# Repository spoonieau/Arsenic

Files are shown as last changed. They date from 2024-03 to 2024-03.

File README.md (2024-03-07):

# Smart HVAC Probe

A ESP32-C3 based probe designed for the the automatic matching of r1234yf, r134, HC-30 and R744 refrigerant pressures from current atmospheric temperature.

## Features
This Probe is designed for the the automatic matching of r1234yf, r134, HC-30 and R744 refrigerant pressures from current atmospheric temperature.

It is also equipped with a vent probe for use automotive air conditioning performance testing.

Charged and programmed over USB -C 

The probe is a fully enabled WiFi device hosting its own micro web server to to display sensor and pressure data. Any device with a WiFi connection and a web browser can connect. 

Once booted the probe will broadcast a WiFi Connection with the details below.

SSID: Smart_Hvac_Probe  
Default Password: Smart_Hvac_Probe  
Probes IP: 192.168.4.1  

Once WiFi connection is established between probe and device, a device the web browser should redirect you the the hosted probes home page. If not, type the probes IP address into a connect web browser address bar.
 
Once at the Probes homepage you can change the WiFi details and set the default units to used by the probe.  
When any setting are updated the Probe will reboot and you device will need to reconnect with the new details. 

## Screenshots
PCB_V3_EE  
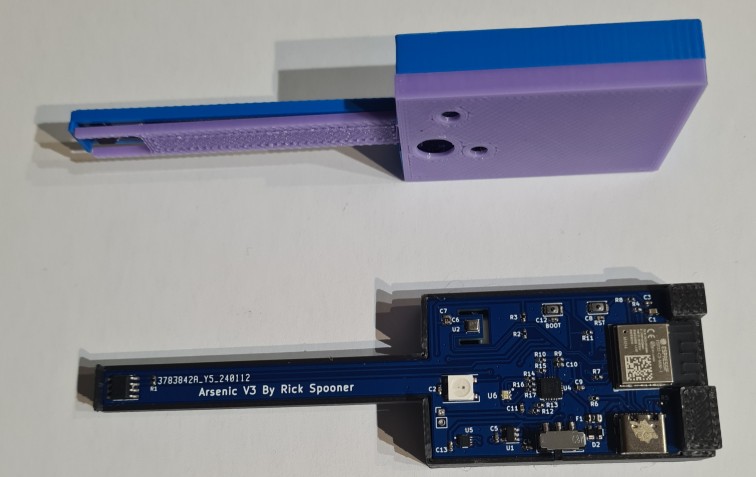
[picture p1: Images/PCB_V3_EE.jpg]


FireFox Mobile  
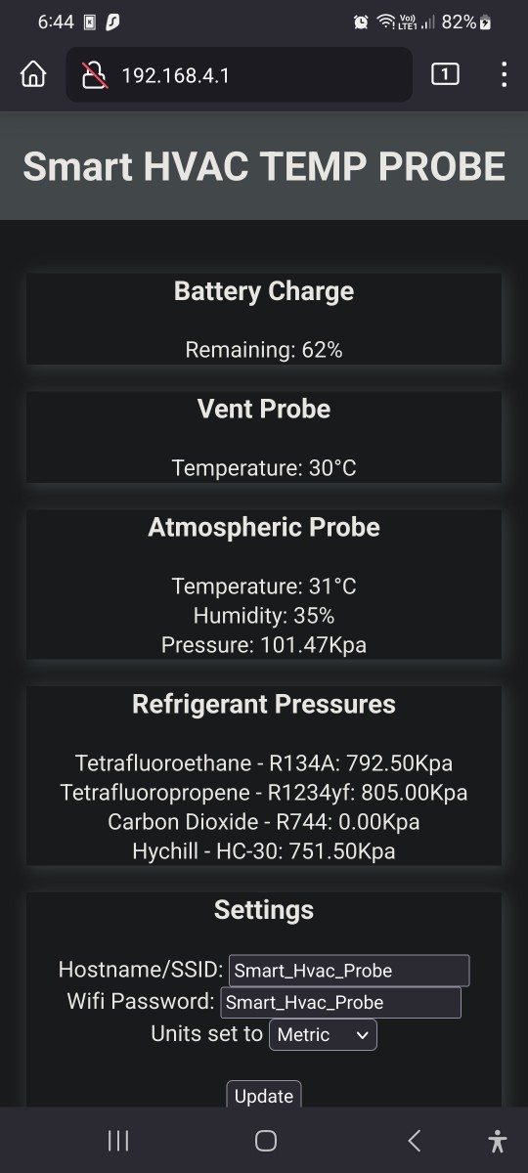
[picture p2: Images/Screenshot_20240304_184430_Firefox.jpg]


FireFox PC  
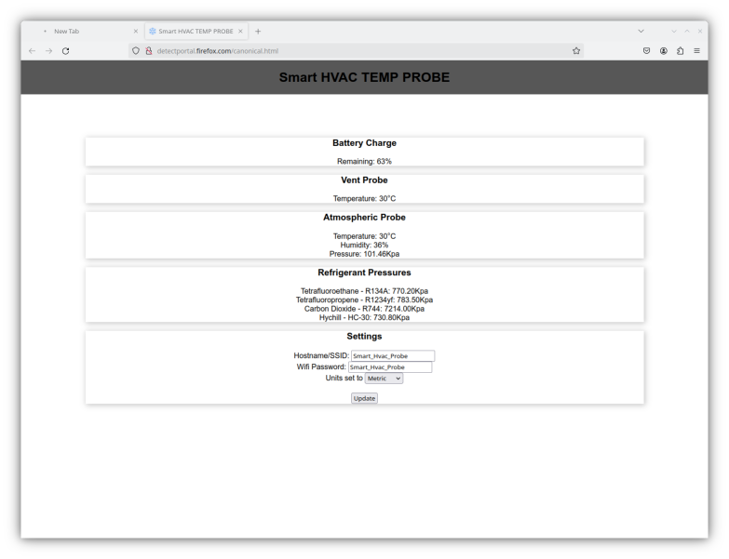
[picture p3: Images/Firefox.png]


## Used Libraries
A huge thankyou to the authors of the libraries used below.  

PaulStoffregen - OneWire  
https://github.com/PaulStoffregen/OneWire

milesburton - Arduino-Temperature-Control-Library  
https://github.com/milesburton/Arduino-Temperature-Control-Library

RadioShuttle - WS2812Led  
https://github.com/RadioShuttle/WS2812Led

hideakitai - MAX17048  
https://github.com/hideakitai/MAX17048

malokhvii-eduard - arduino-bme280  
https://github.com/malokhvii-eduard/arduino-bme280

me-no-dev - ESPAsyncWebServer  
https://github.com/me-no-dev/ESPAsyncWebServer

me-no-dev - AsyncTCP  
https://github.com/me-no-dev/AsyncTCP

arduino-libraries   
https://github.com/arduino-libraries

espressif - arduino-esp32  
https://github.com/espressif/arduino-esp32

## License

Libraries that are used carry their own Licenses.  
Project is released under GPL3

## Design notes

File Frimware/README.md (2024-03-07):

Arsenic Smart HVAC Probe Frimware  
Current is 0.2v for PCB V3

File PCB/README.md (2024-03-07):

KiCad PCB design files for Arsenic Smart HAVC Probe   
Current working version V3

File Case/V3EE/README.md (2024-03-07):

Quick and dirty case made in FreeCad for Arsenic PCB V3

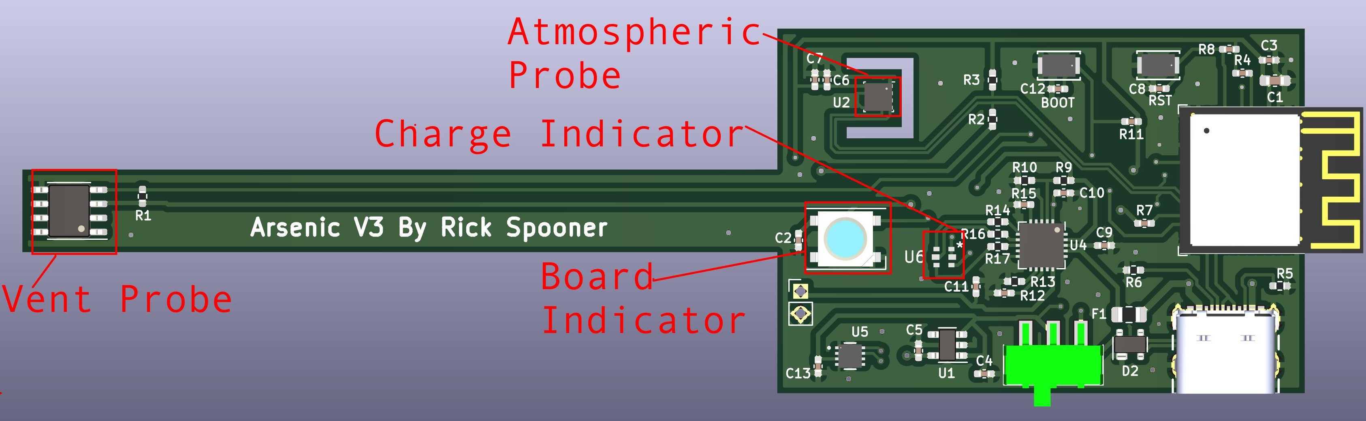
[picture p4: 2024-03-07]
Images/Arsenicv3light.jpg

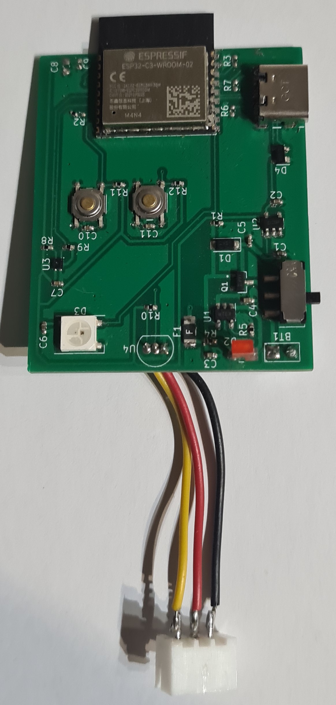
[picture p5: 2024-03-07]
Images/PCB_V1.jpg

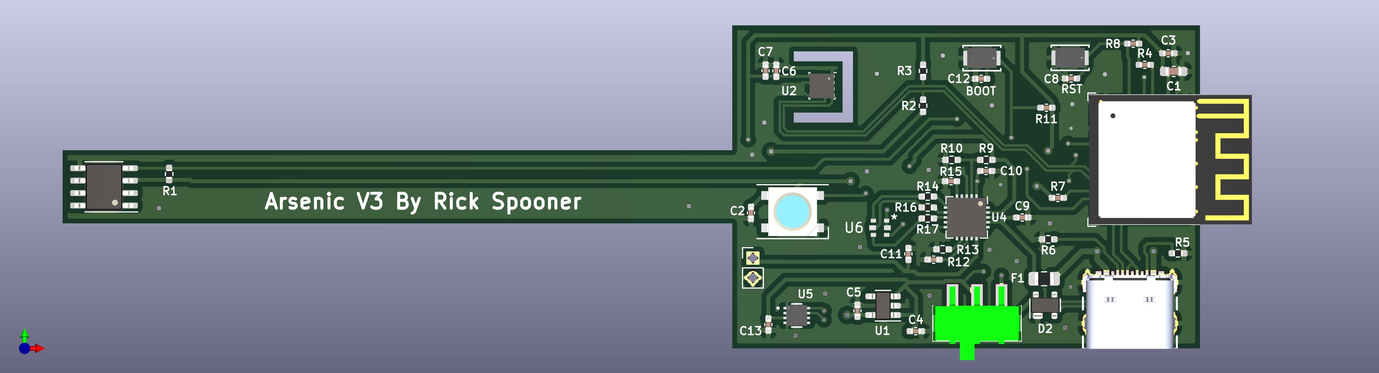
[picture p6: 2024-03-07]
Images/Arsenicv3.jpg

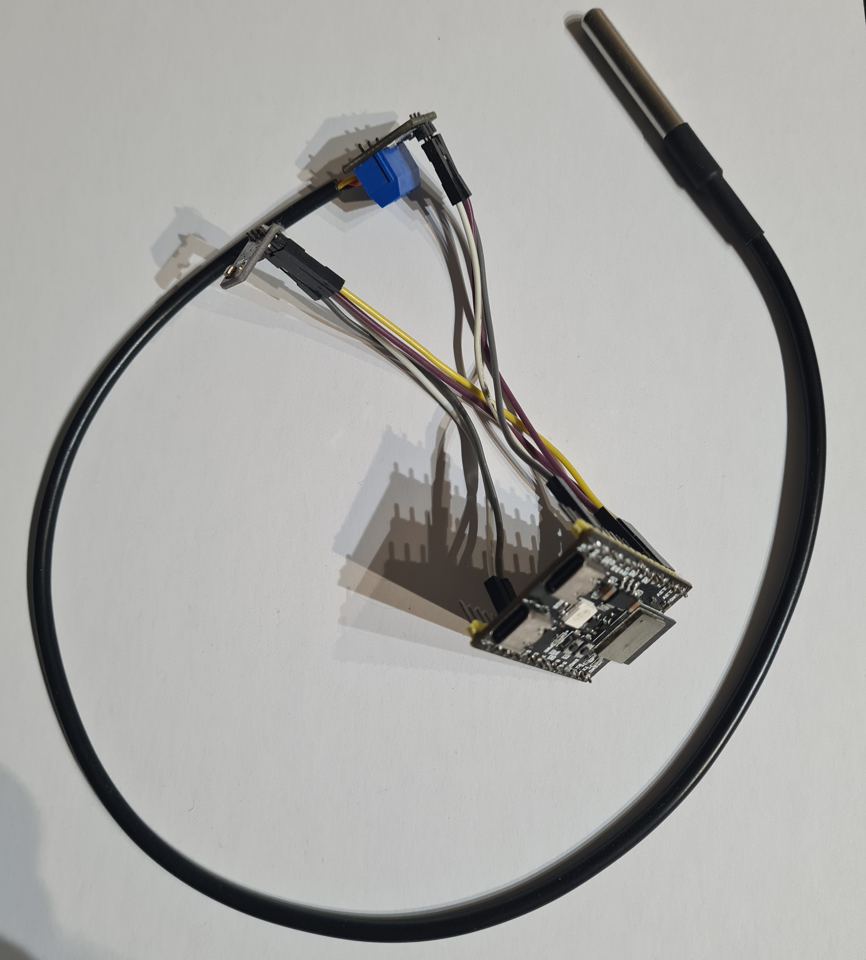
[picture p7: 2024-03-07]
Images/POC_PCB.jpg

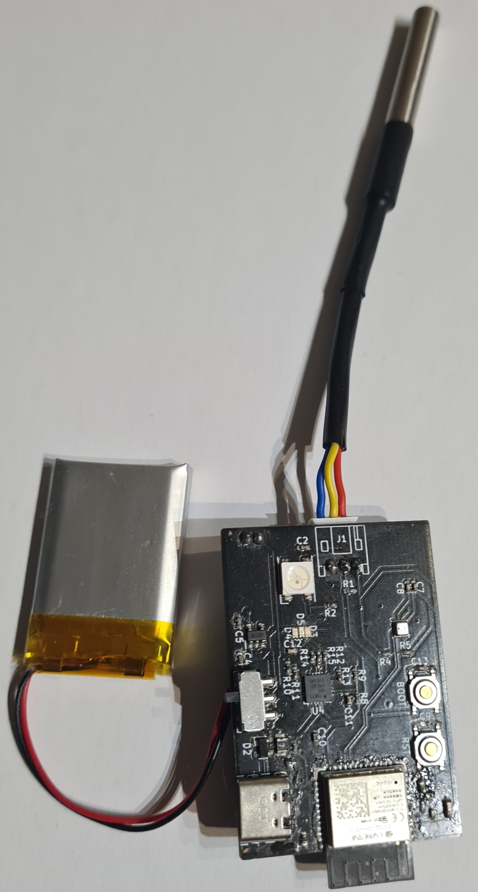
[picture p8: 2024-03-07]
Images/PCV_V2.jpg

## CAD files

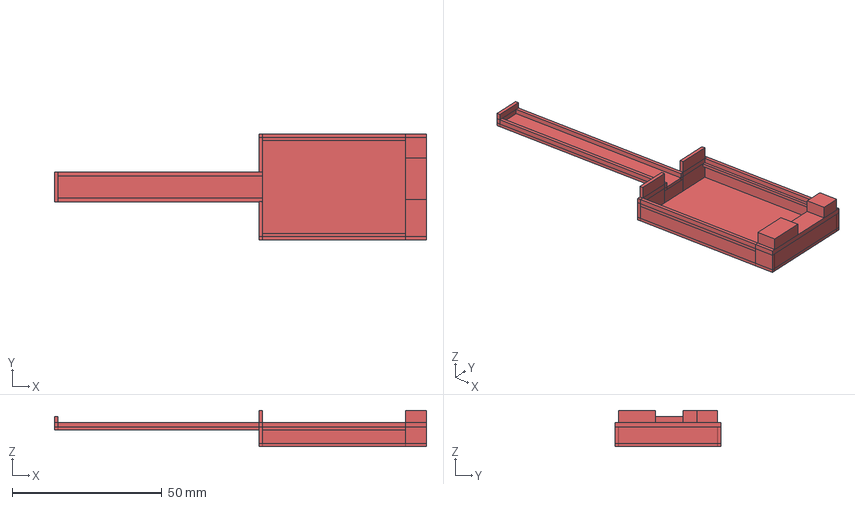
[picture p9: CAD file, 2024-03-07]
Case/V3EE/Arsenic-Case-Bottom.FCStd
124.2 x 35.4 x 12.1 mm
Ruled_Surface
Ruled_Surface001
Ruled_Surface002
Ruled_Surface003
Ruled_Surface004
Ruled_Surface005
Ruled_Surface006
Ruled_Surface007
Ruled_Surface008

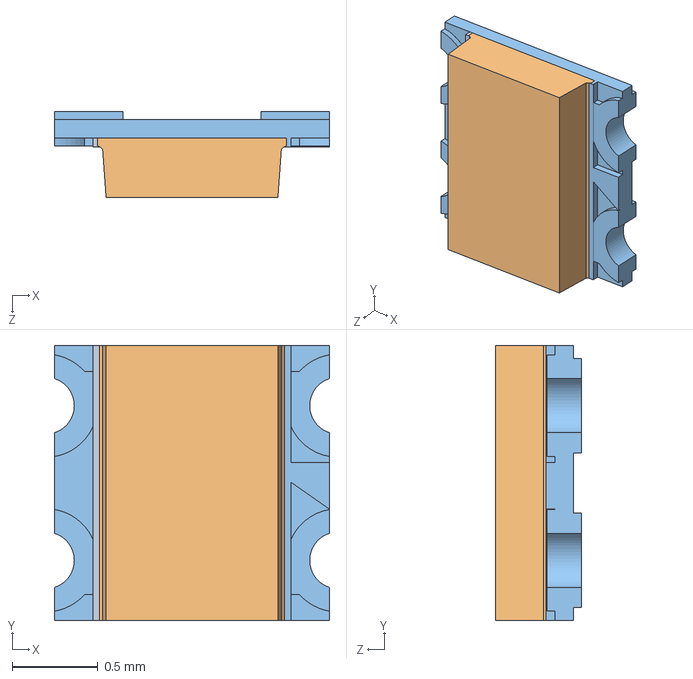
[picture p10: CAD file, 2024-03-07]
PCB/Arsenicv3/Footprints/EAST1616RGBA8/EAST1616RGBA0.STEP
1.60 x 1.60 x 0.5 mm

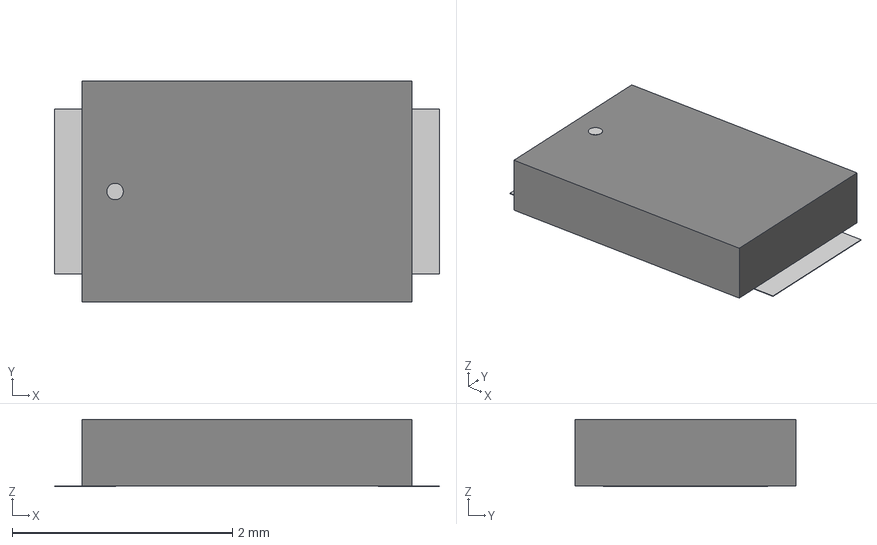
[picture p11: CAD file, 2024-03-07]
PCB/Arsenicv3/Footprints/KXT 331 LHS/KXT321LHS_CNK.step
3.50 x 2.01 x 0.612 mm

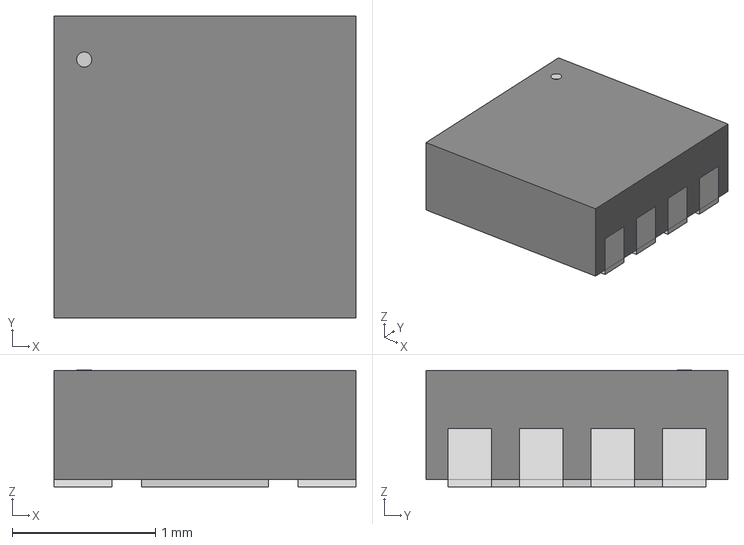
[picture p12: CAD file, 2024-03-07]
PCB/Arsenicv3/Footprints/MAX17048G/21-0168E_T822-3_MXM.step
2.11 x 2.11 x 0.815 mm

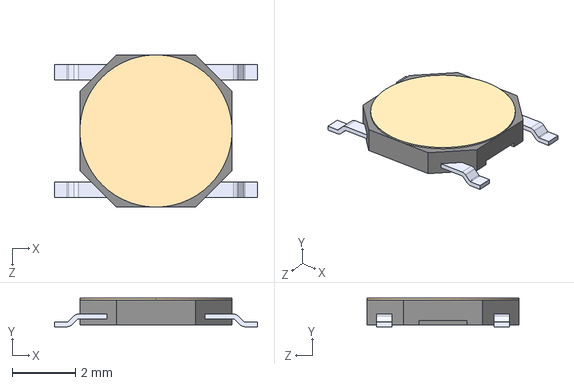
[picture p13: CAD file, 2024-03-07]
PCB/Arsenicv3/Footprints/PTS526_SM15_SMTR2_LFS/PTS526 SM08 SMTR2 LFS--3DModel-STEP-56544.STEP
6.40 x 0.9 x 4.80 mm

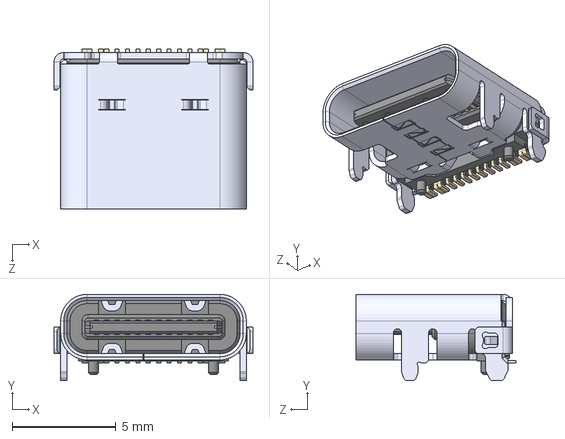
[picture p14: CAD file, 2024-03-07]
PCB/Arsenicv3/Footprints/USB4105-GF-A/USB4105-GF-A.step
9.58 x 4.16 x 7.71 mm

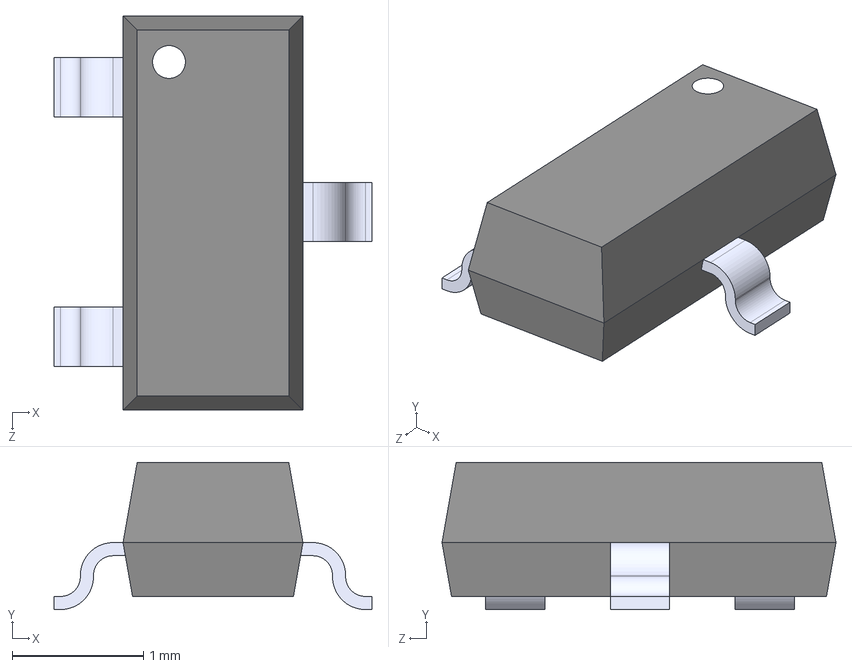
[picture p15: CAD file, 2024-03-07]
PCB/Arsnic/FootPrints/DMP1045U/DMP1045U.step
2.42 x 1.12 x 3.00 mm

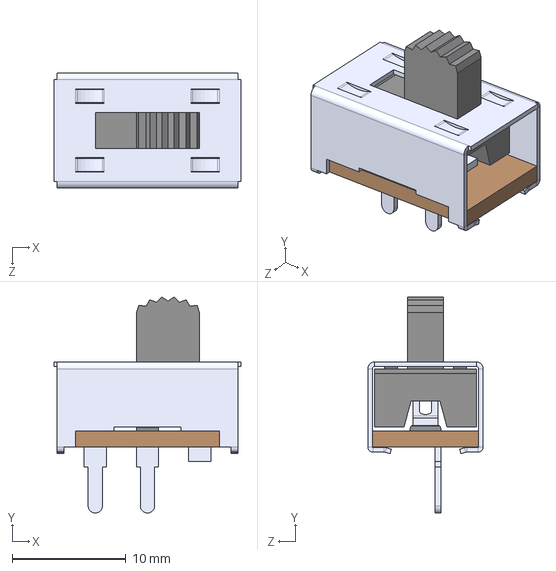
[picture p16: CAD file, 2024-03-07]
PCB/Arsnic/FootPrints/GF-123-0054/GF-123-0054.step
16.5 x 19.0 x 10.2 mm

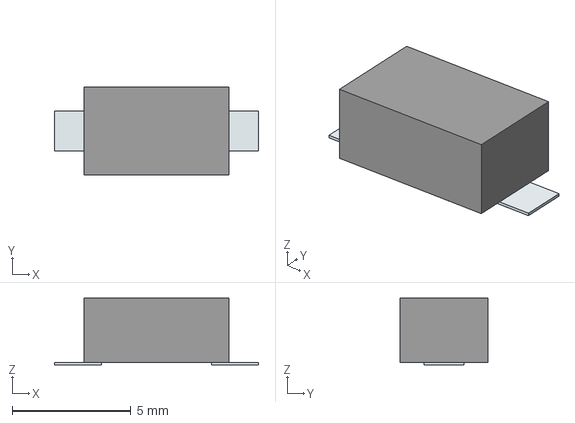
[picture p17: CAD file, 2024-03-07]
PCB/Arsnic/FootPrints/PTS636_SM25F_SMTR_LFS/PTS636_SM25F_SMTR_LFS.step
8.58 x 3.70 x 2.80 mm
Pins

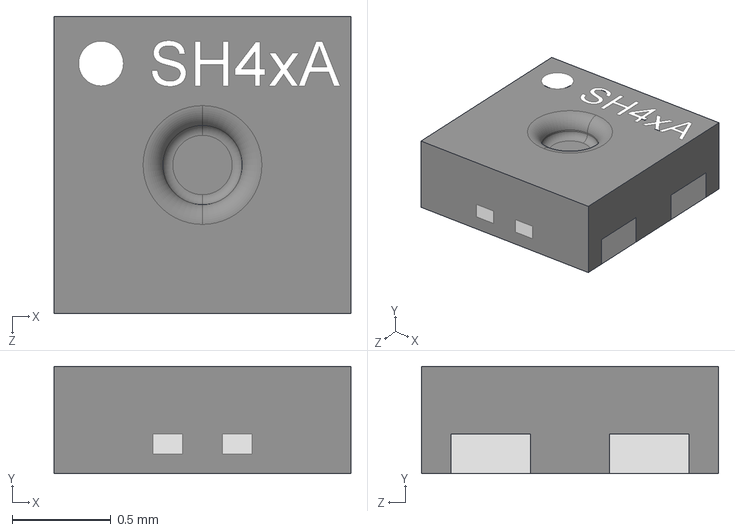
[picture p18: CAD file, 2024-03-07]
PCB/Arsnic/FootPrints/SHT40-AD1B-R3/SHT40-AD1B-R3.step
1.50 x 0.541 x 1.50 mm

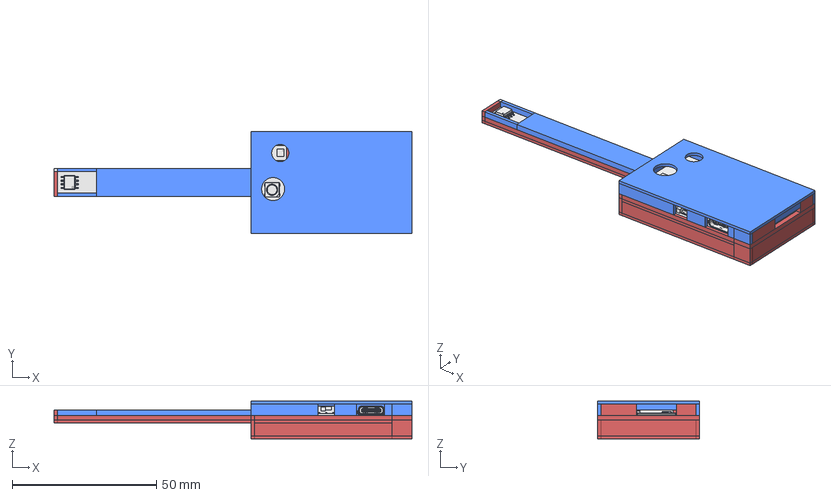
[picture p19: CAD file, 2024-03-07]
Case/V3EE/Arsenic-Case.FCStd
124.2 x 35.4 x 13.1 mm
JS102011SAQN_SW0004_PRT
USB4105
USB4106
USB4107
USB4108
USB4109
USB4110
USB4111
USB4112
USB4113
USB4114
USB4115
USB4116
USB4117
USB4118
USB4119
USB4120
USB4121
USB4122
USB4123
USB4124
USB4125
USB4126
USB4127
USB4128
USB4129
USB4130
USB4131
USB4132
USB4133
USB4134
USB4135
USB4136
USB4137
USB4138
USB4139
USB4140
USB4141
USB4142
USB4143
USB4144
USB4145
USB4146
USB4147
USB4148
ESP32-C3-MINI-1
ESP32-C3-MINI-002
ESP32-C3-MINI-003
ESP32-C3-MINI-004
ESP32-C3-MINI-005
ESP32-C3-MINI-006
ESP32-C3-MINI-007
ESP32-C3-MINI-008
ESP32-C3-MINI-009
ESP32-C3-MINI-010
ESP32-C3-MINI-011
ESP32-C3-MINI-012
ESP32-C3-MINI-013
ESP32-C3-MINI-014
ESP32-C3-MINI-015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

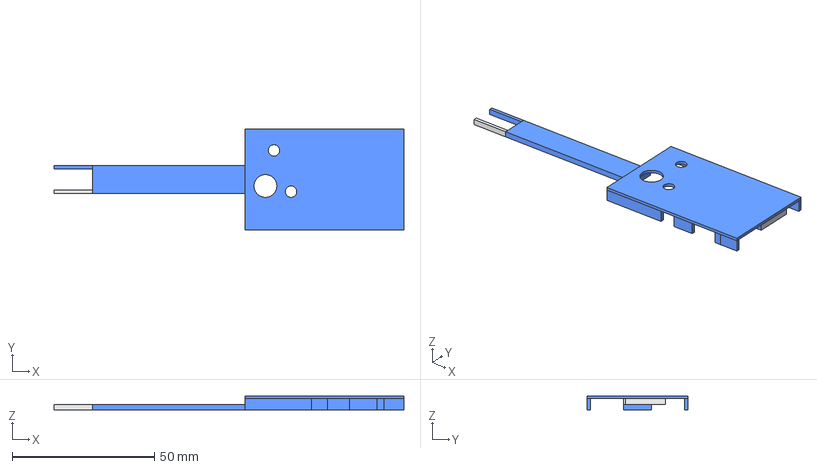
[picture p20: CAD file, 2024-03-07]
Case/V3EE/Arsenic-Case-Top.FCStd
123.0 x 35.4 x 5.00 mm
Ruled_Surface034

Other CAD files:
PCB/Arsenicv3/Footprints/3d/BQ24040DSQR.step
PCB/Arsenicv3/Footprints/3d/JS102011SAQN.step
PCB/Arsenicv3/Footprints/BQ24040DSQR/BQ24040DSQR.step
PCB/Arsenicv3/Footprints/JS102011SAQN/JS102011SAQN--3DModel-Eagle-1.STEP
PCB/Arsenicv3/Footprints/JS102011SAQN/JS102011SAQN.step
PCB/Arsnic/FootPrints/JS102011SAQN/JS102011SAQN.step
PCB/Arsnicv2/Footprints/BQ24040DSQR/BQ24040DSQR.step
PCB/Arsnicv2/Footprints/JS102011SAQN/JS102011SAQN--3DModel-Eagle-1.STEP
PCB/Arsnicv2/Footprints/JS102011SAQN/JS102011SAQN.step

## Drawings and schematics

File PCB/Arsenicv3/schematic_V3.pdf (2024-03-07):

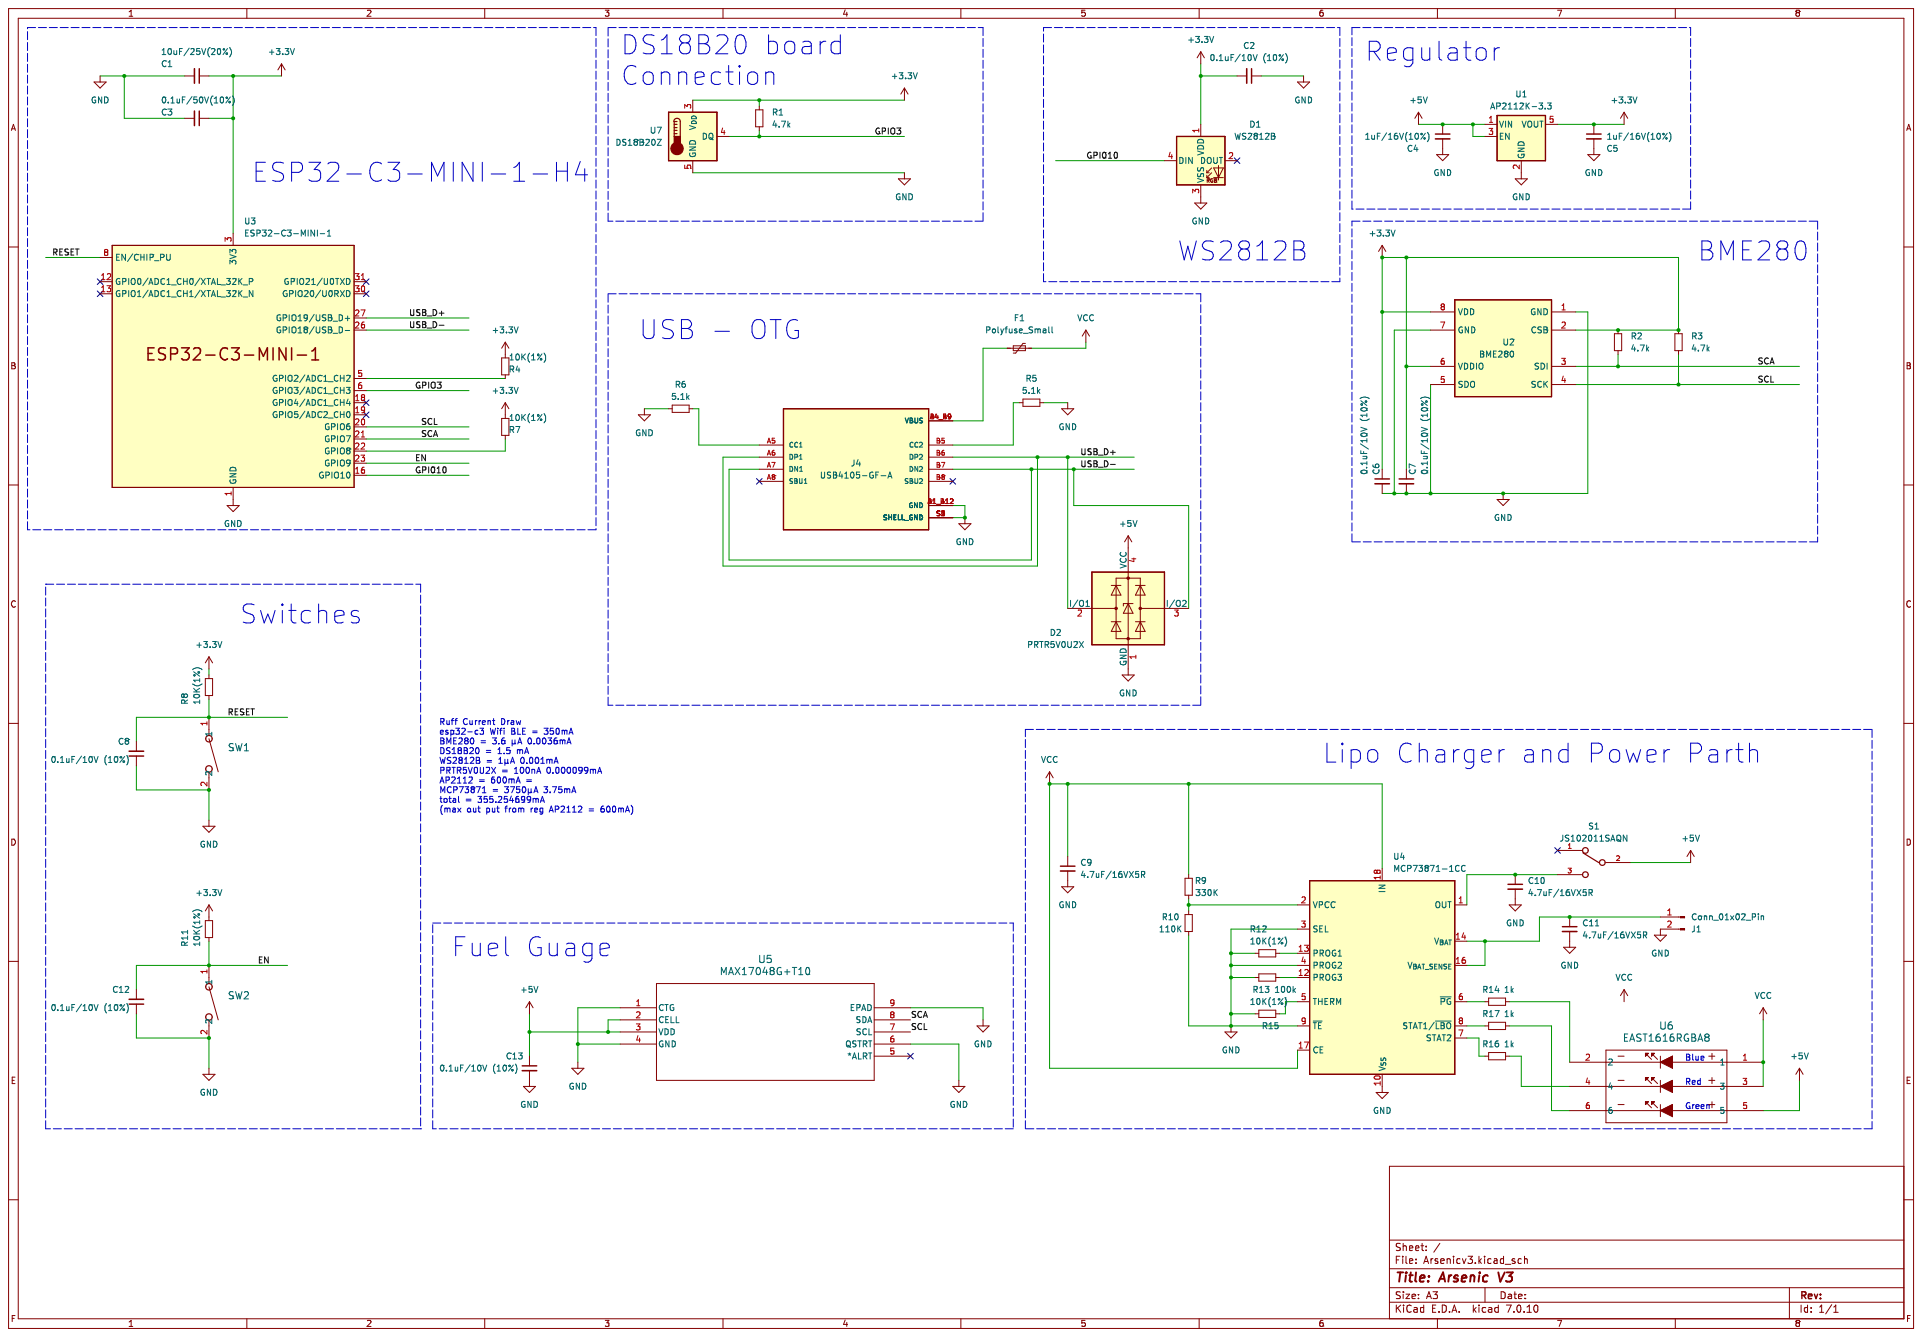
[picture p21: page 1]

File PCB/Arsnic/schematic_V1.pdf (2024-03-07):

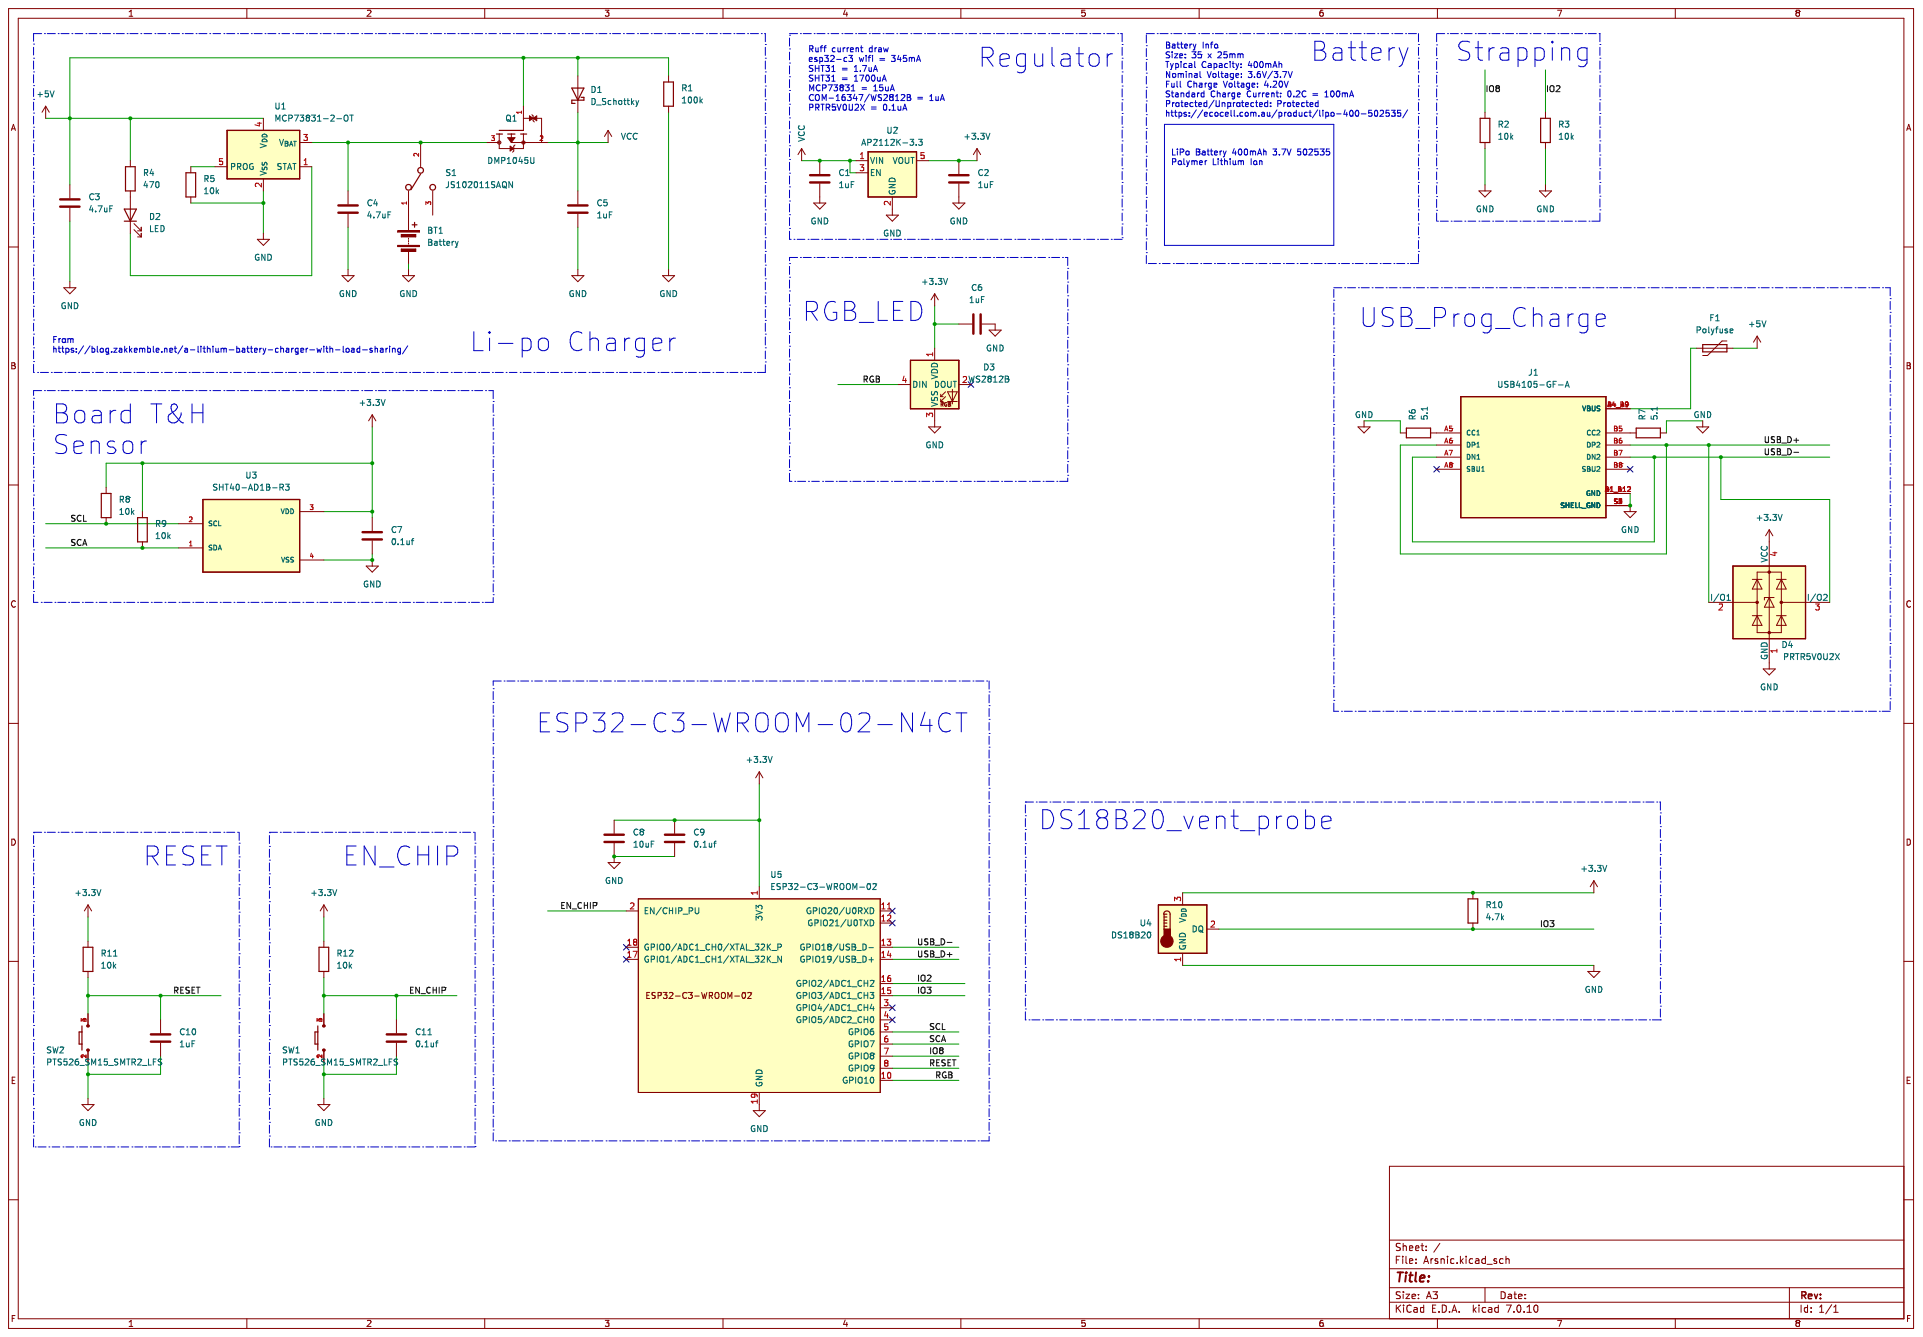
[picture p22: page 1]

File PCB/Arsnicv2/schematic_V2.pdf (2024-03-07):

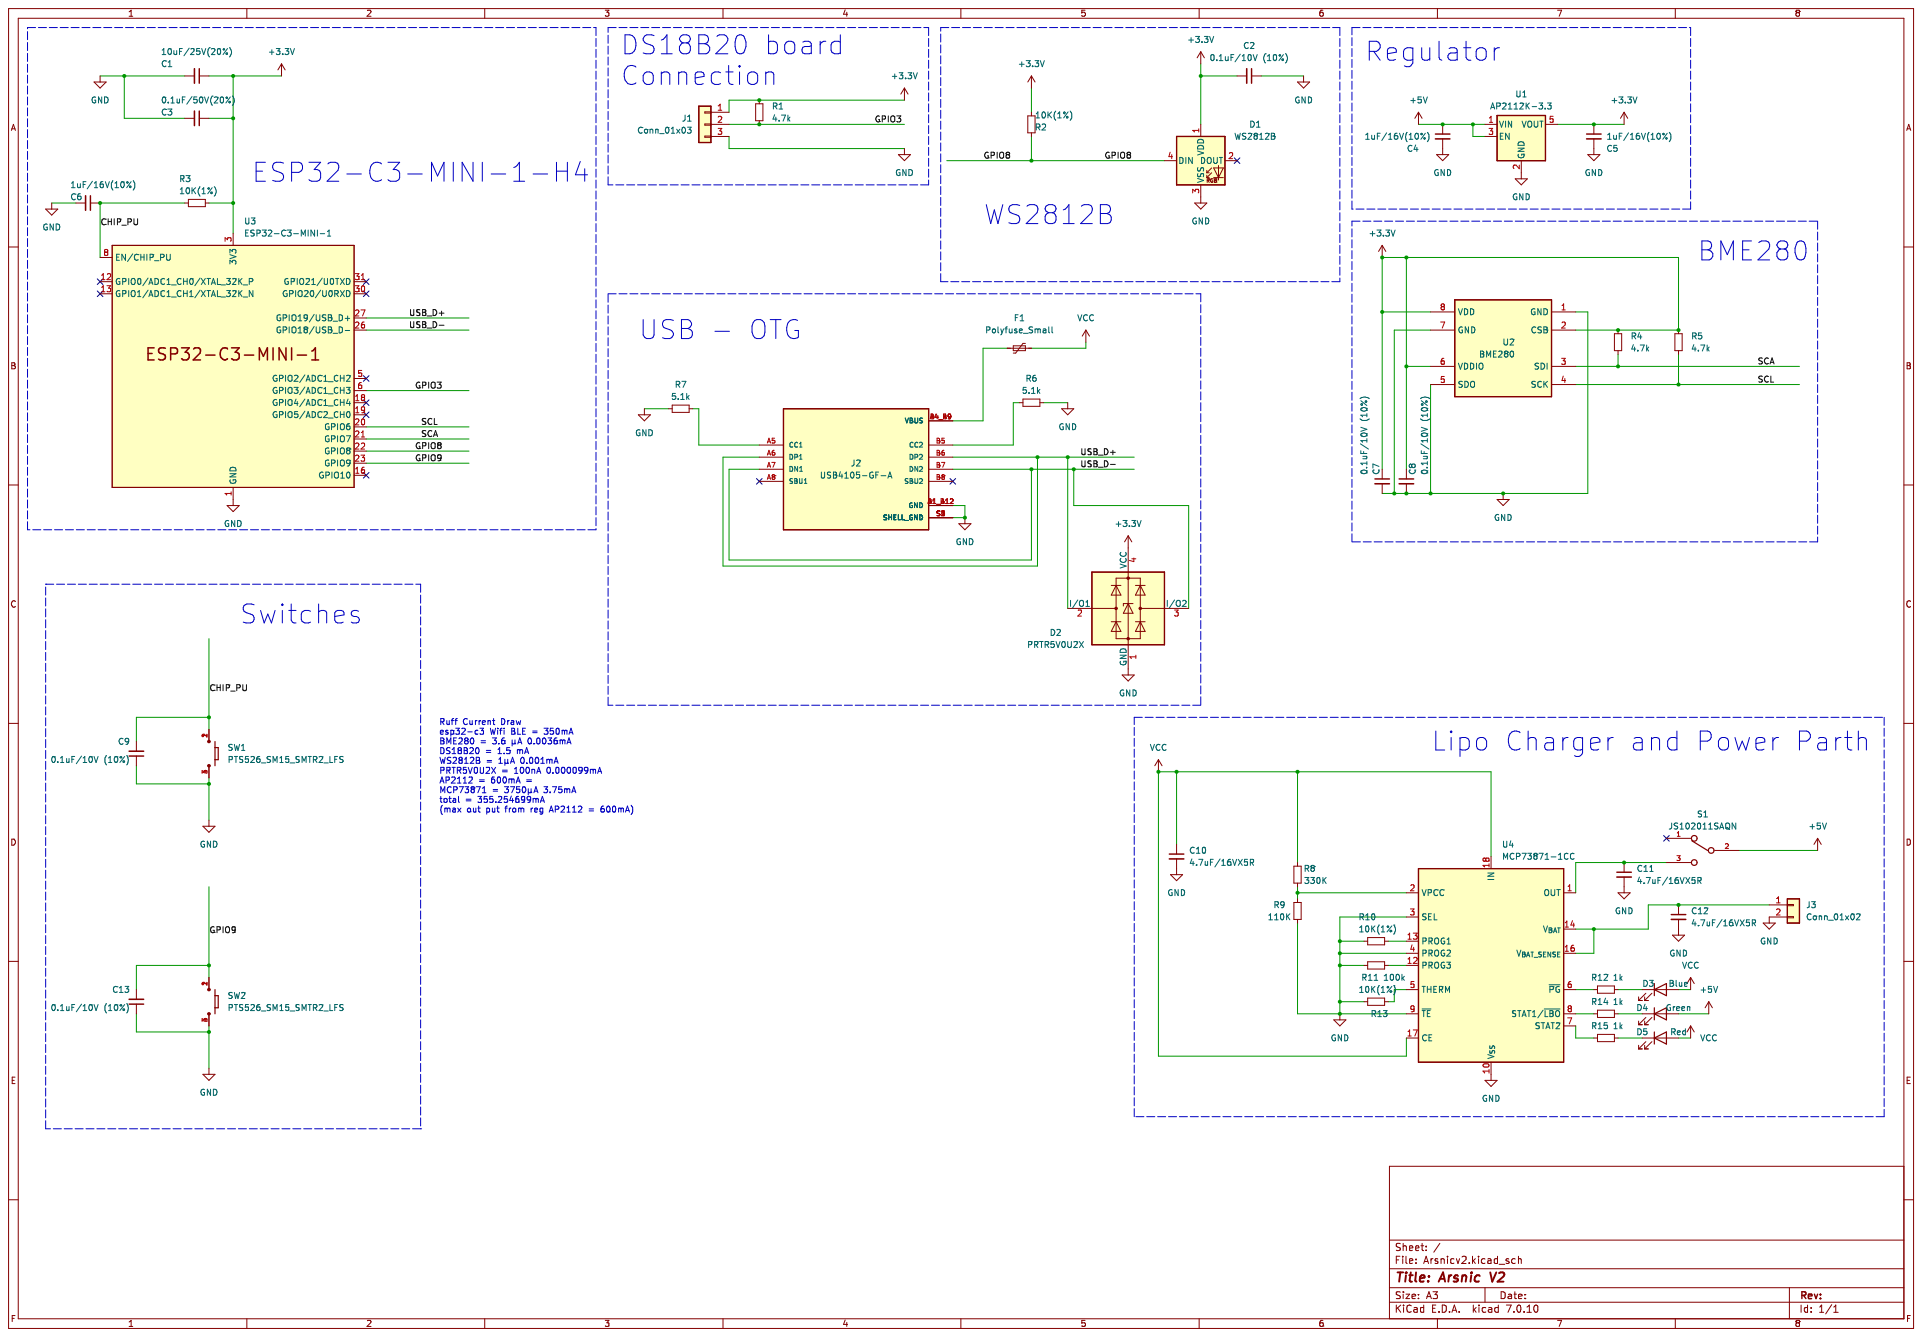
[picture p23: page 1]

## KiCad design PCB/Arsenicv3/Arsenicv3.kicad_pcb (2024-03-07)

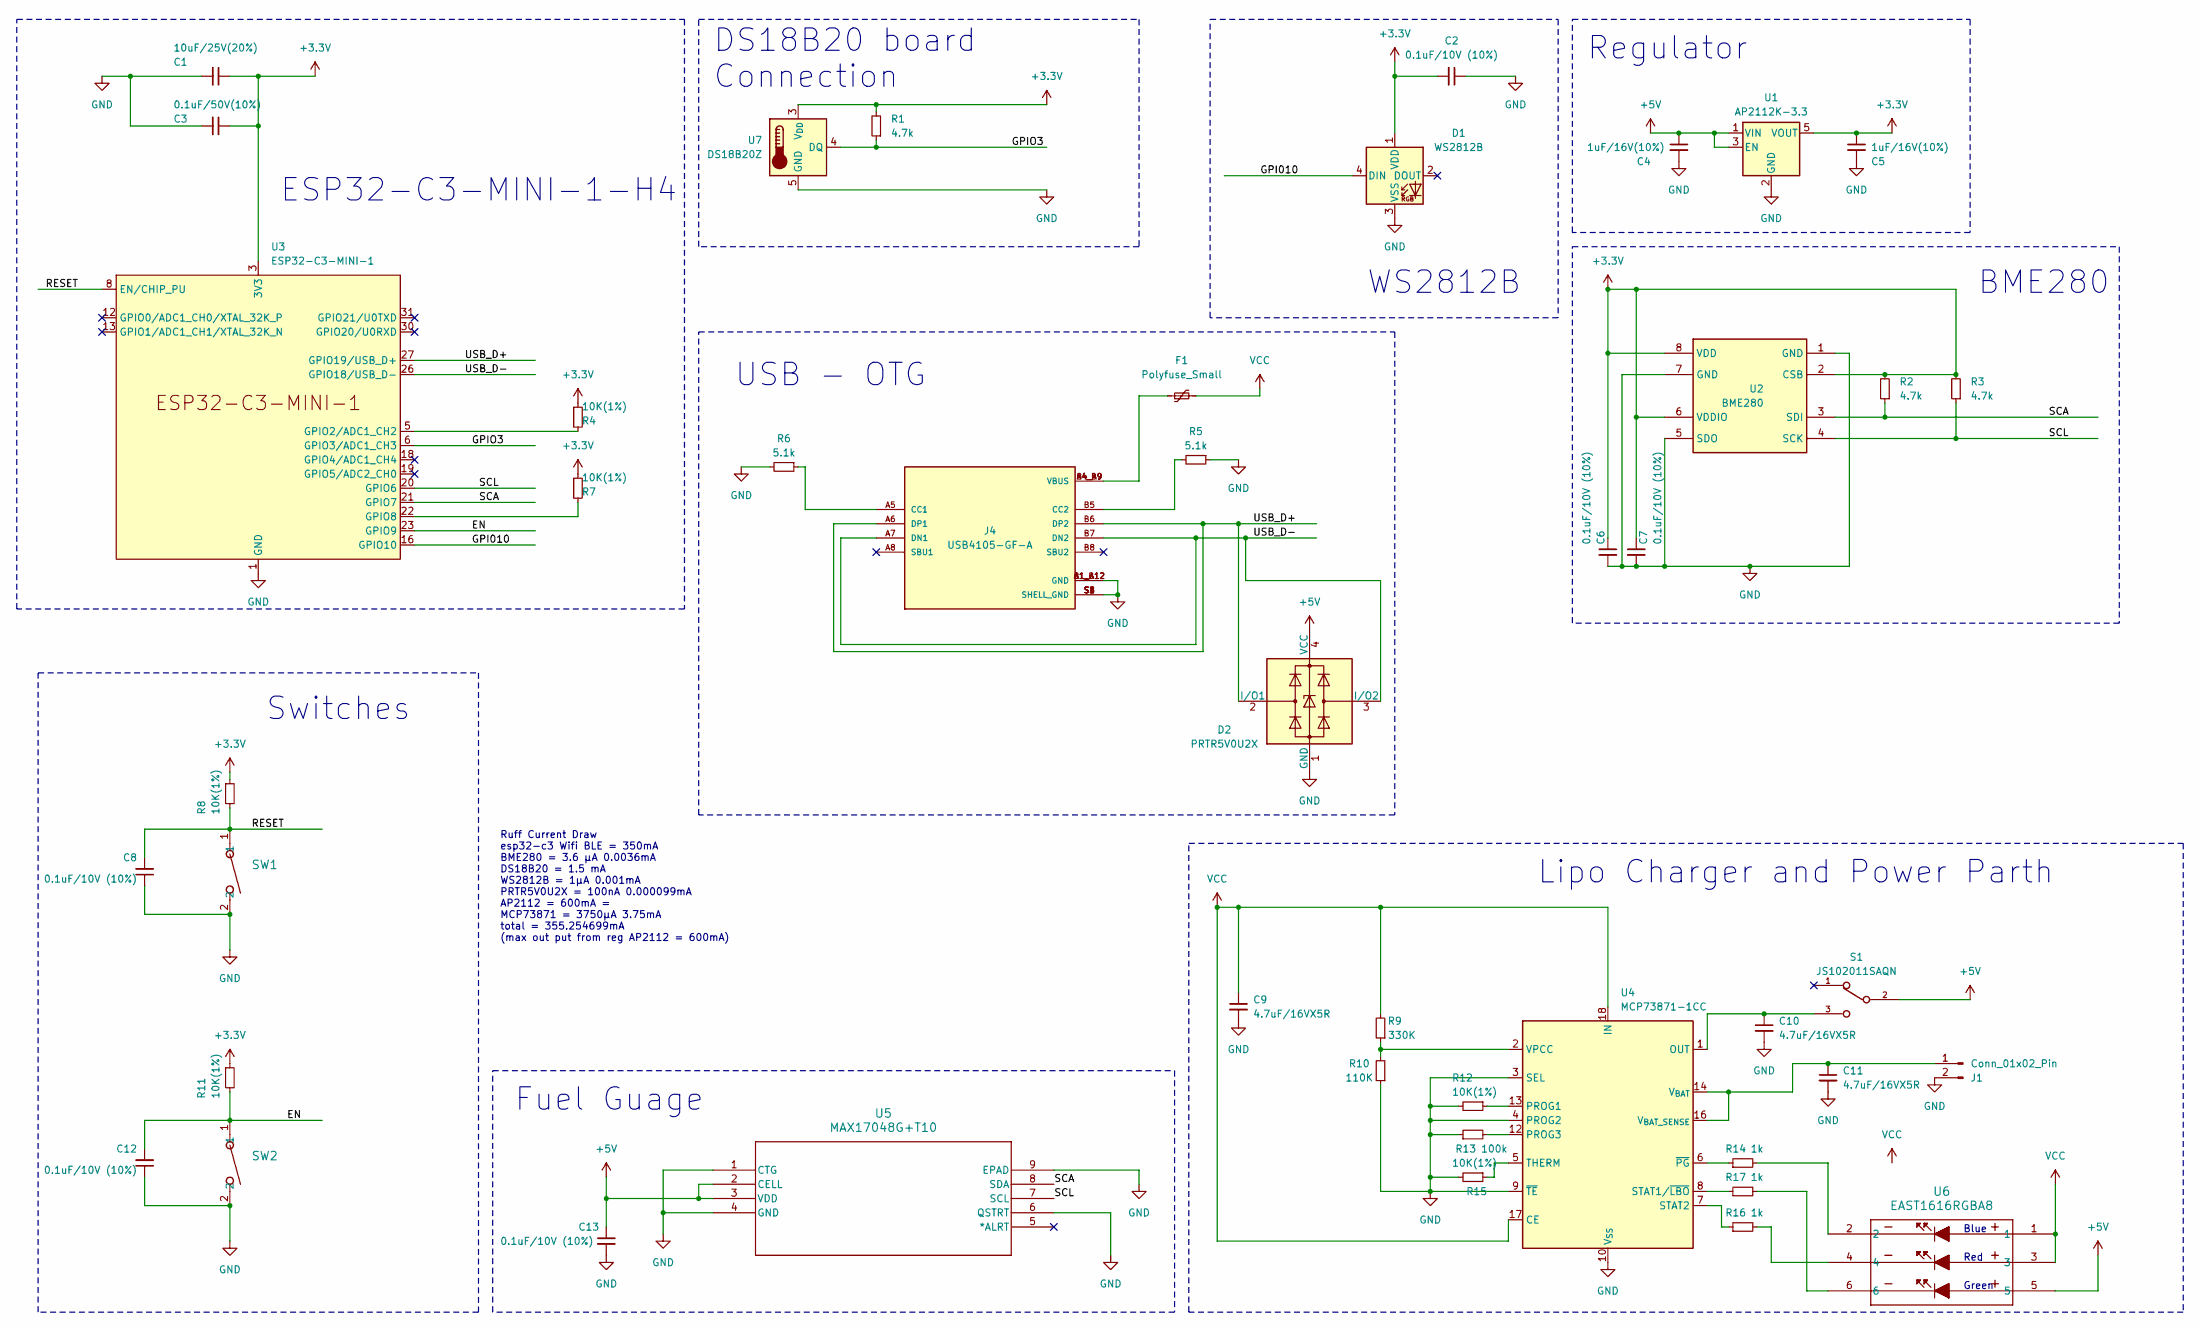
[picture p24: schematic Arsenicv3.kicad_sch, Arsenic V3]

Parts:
C1: 10uF/25V(20%); C_0603_1608Metric_Pad1.08x0.95mm_HandSolder; DigiKeyPN 1276-1869-1-ND
C2, C6, C7, C8, C12, C13: 0.1uF/10V (10%); C_0402_1005Metric_Pad0.74x0.62mm_HandSolder; DigiKeyPN 1276-1022-1-ND
C3: 0.1uF/50V(10%); C_0402_1005Metric_Pad0.74x0.62mm_HandSolder; DigiKeyPN 490-GRM155R61H104ME14DCT-ND
C4, C5: 1uF/16V(10%); C_0402_1005Metric_Pad0.74x0.62mm_HandSolder; DigiKeyPN 1276-1067-1-ND
C9, C10, C11: 4.7uF/16VX5R; C_0402_1005Metric_Pad0.74x0.62mm_HandSolder; DigiKeyPN 478-CM05X5R475M16AHCT-ND
D1: WS2812B; LED_WS2812B_PLCC4_5.0x5.0mm_P3.2mm; DigiKeyPN 1568-COM-16347CT-ND
D2: PRTR5V0U2X; SOT-143; DigiKeyPN 1727-3884-1-ND
F1: Polyfuse_Small; Fuse_0805_2012Metric_Pad1.15x1.40mm_HandSolder; DigiKeyPN 13-SMD0805B075TFCT-ND
J1: Conn_01x02_Pin; PinHeader_1x02_P2.00mm_Vertical
J4: USB4105-GF-A; GCT_USB4105-GF-A; DigiKeyPN 2073-USB4105-GF-ACT-ND
R1, R2, R3: 4.7k; R_0402_1005Metric_Pad0.72x0.64mm_HandSolder; DigiKeyPN 311-4.7KLRCT-ND
R4, R7, R8, R11, R12, R15: 10K(1%); C_0402_1005Metric_Pad0.74x0.62mm_HandSolder; DigiKeyPN 311-10.0KLRCT-ND
R5, R6: 5.1k; R_0402_1005Metric_Pad0.72x0.64mm_HandSolder; DigiKeyPN 13-RC0402FR-135K1LCT-ND
R9: 330K; R_0402_1005Metric_Pad0.72x0.64mm_HandSolder; DigiKeyPN 1292-WR04X3303FTLCT-ND
R10: 110K; R_0402_1005Metric_Pad0.72x0.64mm_HandSolder; DigiKeyPN CR0402-FX-1103GLFCT-ND
R13: 100k; R_0402_1005Metric_Pad0.72x0.64mm_HandSolder; DigiKeyPN 311-100KLRCT-ND
R14, R16, R17: 1k; R_0402_1005Metric_Pad0.72x0.64mm_HandSolder; DigiKeyPN 311-1.00KLRCT-ND
S1: JS102011SAQN; SW_JS102011SAQN; DigiKeyPN 401-1999-1-ND
SW1, SW2: KXT331LHS; KXT3_CNK; DigiKeyPN CKN10779CT-ND
U1: AP2112K-3.3; SOT-23-5; DigiKeyPN AP2112K-3.3TRG1DICT-ND
U2: BME280; Bosch_LGA-8_2.5x2.5mm_P0.65mm_ClockwisePinNumbering; DigiKeyPN 828-1063-1-ND
U3: ESP32-C3-MINI-1; DigiKeyPN 1965-ESP32-C3-MINI-1-H4CT-ND
U4: MCP73871-1CC; QFN-20-1EP_4x4mm_P0.5mm_EP2.5x2.5mm; DigiKeyPN MCP73871-1CCI/ML-ND
U5: MAX17048G+T10; 21-0168E_T822-3_MXM; DigiKeyPN MAX17048G+T10CT-ND
U6: EAST1616RGBA8; LED_EAST1616RGBA8; DigiKeyPN 1080-EAST1616RGBA8CT-ND
U7: DS18B20Z; SOIC-8_3.9x4.9mm_P1.27mm; DigiKeyPN 4518-DS18B20ZCT-ND

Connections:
+3.3V: C1.1, C2.2, C3.1, C5.1, C6.1, C7.1, D1.1 (VDD), R1.2, R2.2, R3.2, R4.1, R7.1, R8.1, R11.1, U1.5 (VOUT), U2.2 (CSB), U2.6 (VDDIO), U2.8 (VDD), U3.3 (3V3), U7.3 (V_{DD})
+5V: C4.1, C13.1, D2.4 (VCC), S1.2, U1.1 (VIN), U1.3 (EN), U5.2 (CELL), U5.3 (VDD), U6.5
/EN: C12.2, R11.2, SW2.1, U3.23 (GPIO9)
/GPI010: D1.4 (DIN), U3.16 (GPIO10)
/GPIO3: R1.1, U3.6 (GPIO3/ADC1_CH3), U7.4 (DQ)
/RESET: C8.2, R8.2, SW1.1, U3.8 (EN/CHIP_PU)
/SCA: R2.1, U2.3 (SDI), U3.21 (GPIO7), U5.8 (SDA)
/SCL: R3.1, U2.4 (SCK), U3.20 (GPIO6), U5.7 (SCL)
/USB_D+: D2.2 (I/O1), J4.A6 (DP1), J4.B6 (DP2), U3.27 (GPIO19/USB_D+)
/USB_D-: D2.3 (I/O2), J4.A7 (DN1), J4.B7 (DN2), U3.26 (GPIO18/USB_D-)
GND: C1.2, C2.1, C3.2, C4.2, C5.2, C6.2, C7.2, C8.1, C9.2, C10.2, C11.2, C12.1, C13.2, D1.3 (VSS), D2.1 (GND), J1.2, J4.A1_B12 (GND), J4.B1_A12 (GND), J4.S1 (SHELL_GND), J4.S2 (SHELL_GND), J4.S3 (SHELL_GND), J4.S4 (SHELL_GND), R5.1, R6.2, R10.1, R12.2, R13.1, R15.2, SW1.2, SW2.2, U1.2 (GND), U2.1 (GND), U2.5 (SDO), U2.7 (GND), U3.1 (GND), U3.2 (GND), U3.11 (GND), U3.14 (GND), U3.36 (GND), U3.37 (GND), U3.38 (GND), U3.39 (GND), U3.40 (GND), U3.41 (GND), U3.42 (GND), U3.43 (GND), U3.44 (GND), U3.45 (GND), U3.46 (GND), U3.47 (GND), U3.48 (GND), U3.49 (GND), U3.50 (GND), U3.51 (GND), U3.52 (GND), U3.53 (GND), U4.3 (SEL), U4.4 (PROG2), U4.9 (~TE), U4.10 (V_{SS}), U4.11 (V_{SS}), U4.21 (V_{SS}), U5.1 (CTG), U5.4 (GND), U5.6 (QSTRT), U5.9 (EPAD), U7.5 (GND)
unnamed: C10.1, S1.3, U4.1 (OUT), U4.20 (OUT)
unnamed: F1.1, J4.A4_B9 (VBUS), J4.B4_A9 (VBUS)
unnamed: C11.1, J1.1, U4.14 (V_{BAT}), U4.15 (V_{BAT}), U4.16 (V_{BAT_SENSE})
unnamed: J4.A5 (CC1), R6.1
unnamed: J4.B5 (CC2), R5.2
unnamed: R14.2, U6.2
unnamed: R16.2, U6.4
unnamed: R17.2, U6.6
unnamed: R4.2, U3.5 (GPIO2/ADC1_CH2)
unnamed: R7.2, U3.22 (GPIO8)
unnamed: R12.1, U4.13 (PROG1)
unnamed: R13.2, U4.12 (PROG3)
unnamed: R17.1, U4.8 (STAT1/~LBO)
unnamed: R16.1, U4.7 (STAT2)
unnamed: R15.1, U4.5 (THERM)
unnamed: R9.1, R10.2, U4.2 (VPCC)
unnamed: R14.1, U4.6 (~PG)
VCC: C9.1, F1.2, R9.2, U4.17 (CE), U4.18 (IN), U4.19 (IN), U6.1, U6.3

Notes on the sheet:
WS2812B
Regulator
Fuel Guage
Lipo Charger and Power Parth
Green
USB - OTG
ESP32-C3-MINI-1-H4
BME280
Switches
Red
Blue
Ruff Current Draw esp32-c3 Wifi BLE = 350mA BME280 = 3.6 μA 0.0036mA DS18B20 = 1.5 mA WS2812B = 1μA 0.001mA PRTR5V0U2X = 100nA 0.000099mA AP2112 = 600mA = MCP73871 = 3750μA 3.75mA total = 355.254699mA (max out put from reg AP2112 = 600mA)
DS18B20 board Connection

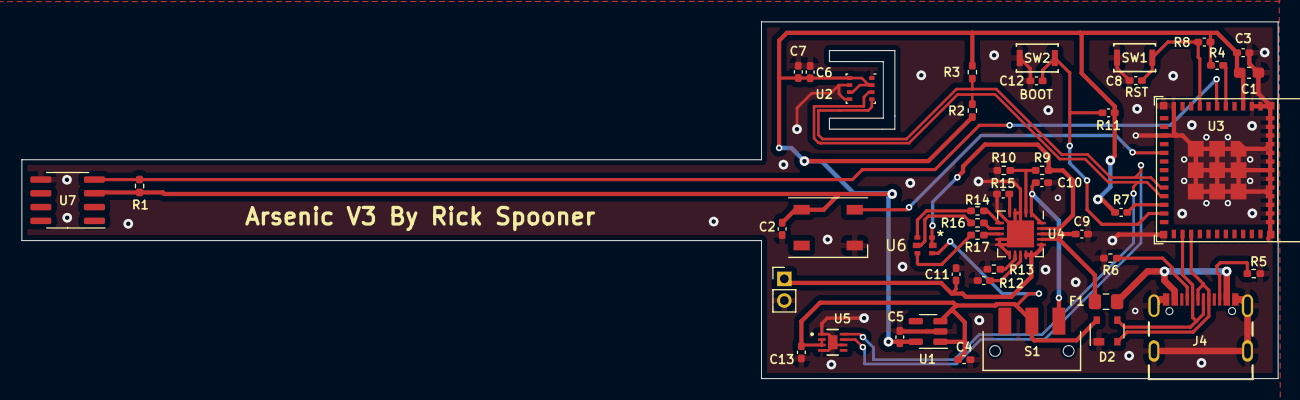
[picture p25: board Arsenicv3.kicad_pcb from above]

Board: 2 copper layers, 116.0 x 33.0 mm, 45 parts (0 on the bottom side), 29 nets.

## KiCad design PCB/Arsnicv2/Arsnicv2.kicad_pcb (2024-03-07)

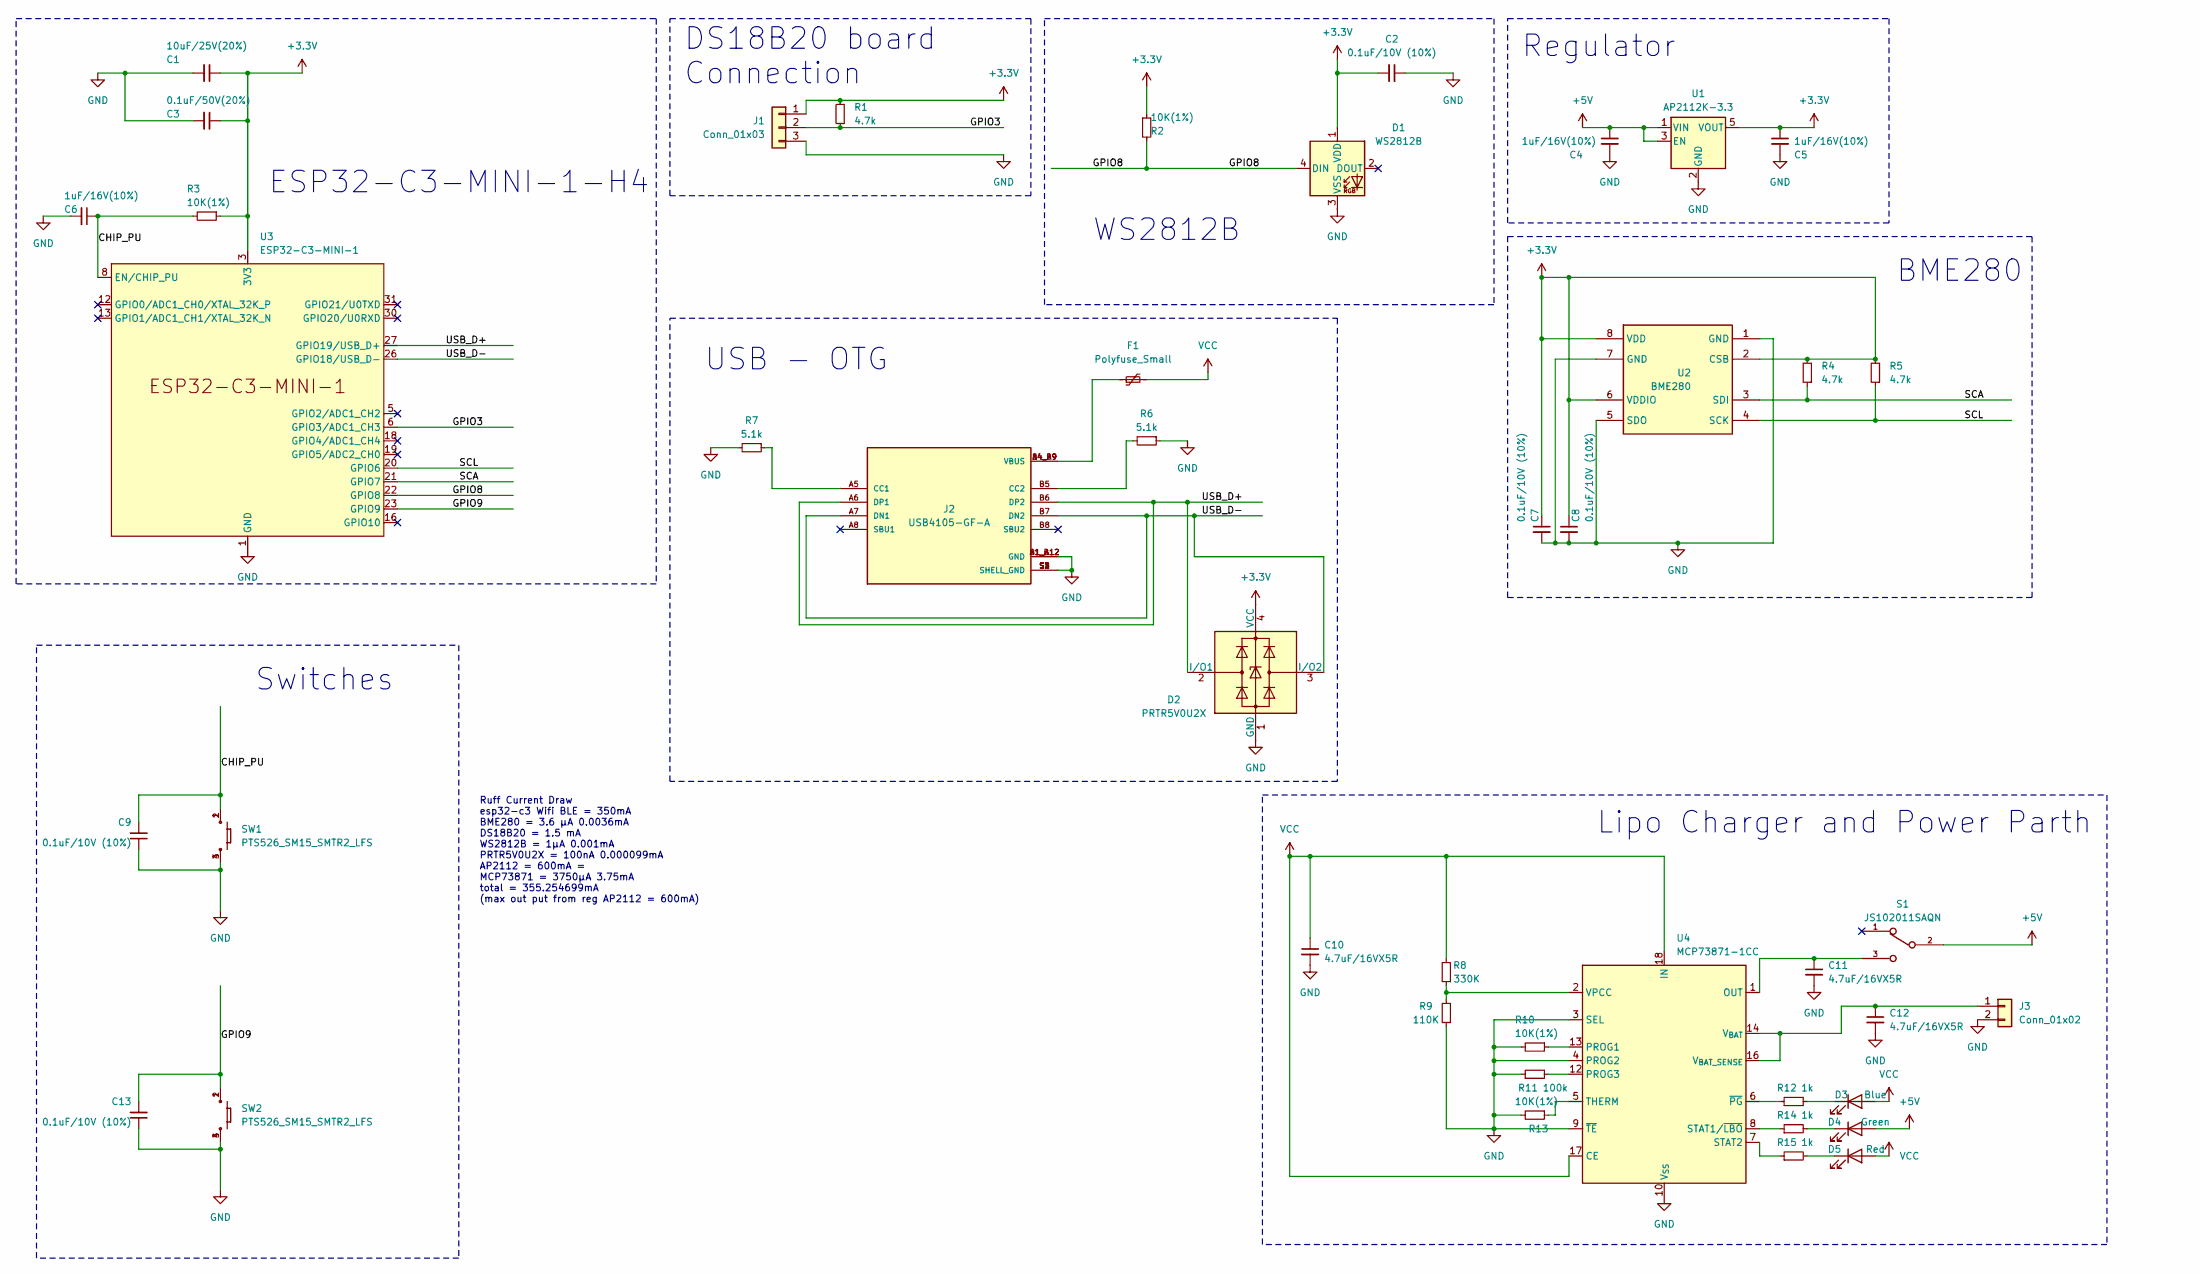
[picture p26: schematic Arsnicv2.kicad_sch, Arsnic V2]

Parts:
C1: 10uF/25V(20%); C_0603_1608Metric_Pad1.08x0.95mm_HandSolder; DigiKeyPN 1276-1869-1-ND
C2, C7, C8, C9, C13: 0.1uF/10V (10%); C_0402_1005Metric_Pad0.74x0.62mm_HandSolder; DigiKeyPN 1276-1022-1-ND
C3: 0.1uF/50V(20%); C_0402_1005Metric_Pad0.74x0.62mm_HandSolder; DigiKeyPN 490-GRM155R61H104ME14DCT-ND
C4, C5, C6: 1uF/16V(10%); C_0402_1005Metric_Pad0.74x0.62mm_HandSolder; DigiKeyPN 1276-1067-1-ND
C10, C11, C12: 4.7uF/16VX5R; C_0402_1005Metric_Pad0.74x0.62mm_HandSolder; DigiKeyPN 478-CM05X5R475M16AHCT-ND
D1: WS2812B; LED_WS2812B_PLCC4_5.0x5.0mm_P3.2mm; DigiKeyPN 1568-COM-16347CT-ND
D2: PRTR5V0U2X; SOT-143; DigiKeyPN 1727-3884-1-ND
D3: Blue; LED_0201_0603Metric_Pad0.64x0.40mm_HandSolder; DigiKeyPN 1830-1068-1-ND
D4: Green; LED_0201_0603Metric_Pad0.64x0.40mm_HandSolder; DigiKeyPN 1830-1069-1-ND
D5: Red; LED_0201_0603Metric_Pad0.64x0.40mm_HandSolder; DigiKeyPN 1830-1072-1-ND
F1: Polyfuse_Small; Fuse_0805_2012Metric_Pad1.15x1.40mm_HandSolder; DigiKeyPN 13-SMD0805B075TFCT-ND
J1: Conn_01x03; JST_PH_S3B-PH-K_1x03_P2.00mm_Horizontal; DigiKeyPN S3B-PH-K-S-GW-ND
J2: USB4105-GF-A; GCT_USB4105-GF-A; DigiKeyPN 2073-USB4105-GF-ACT-ND
J3: Conn_01x02; JST_PH_S2B-PH-K_1x02_P2.00mm_Horizontal; DigiKeyPN 455-1719-ND
R1, R4, R5: 4.7k; R_0402_1005Metric_Pad0.72x0.64mm_HandSolder; DigiKeyPN 311-4.7KLRCT-ND
R2, R3, R10, R13: 10K(1%); C_0402_1005Metric_Pad0.74x0.62mm_HandSolder; DigiKeyPN 311-10.0KLRCT-ND
R6, R7: 5.1k; R_0402_1005Metric_Pad0.72x0.64mm_HandSolder; DigiKeyPN 13-RC0402FR-135K1LCT-ND
R8: 330K; R_0402_1005Metric_Pad0.72x0.64mm_HandSolder; DigiKeyPN 1292-WR04X3303FTLCT-ND
R9: 110K; R_0402_1005Metric_Pad0.72x0.64mm_HandSolder; DigiKeyPN CR0402-FX-1103GLFCT-ND
R11: 100k; R_0402_1005Metric_Pad0.72x0.64mm_HandSolder; DigiKeyPN 311-100KLRCT-ND
R12, R14, R15: 1k; R_0402_1005Metric_Pad0.72x0.64mm_HandSolder; DigiKeyPN 311-1.00KLRCT-ND
S1: JS102011SAQN; SW_JS102011SAQN; DigiKeyPN 401-1999-1-ND
SW1, SW2: PTS526_SM15_SMTR2_LFS; PTS526SM15SMTR2LFS; DigiKeyPN CKN12220-1-ND
U1: AP2112K-3.3; SOT-23-5; DigiKeyPN AP2112K-3.3TRG1DICT-ND
U2: BME280; Bosch_LGA-8_2.5x2.5mm_P0.65mm_ClockwisePinNumbering; DigiKeyPN 828-1063-1-ND
U3: ESP32-C3-MINI-1; ESP32-C3-MINI-1_HandSoldering; DigiKeyPN 1965-ESP32-C3-MINI-1-H4CT-ND
U4: MCP73871-1CC; QFN-20-1EP_4x4mm_P0.5mm_EP2.5x2.5mm; DigiKeyPN MCP73871-1CCI/ML-ND

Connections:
+3.3V: C1.1, C2.2, C3.1, C5.1, C7.1, C8.1, D1.1 (VDD), D2.4 (VCC), J1.1, R1.2, R2.1, R3.1, R4.2, R5.2, U1.5 (VOUT), U2.2 (CSB), U2.6 (VDDIO), U2.8 (VDD), U3.3 (3V3)
+5V: C4.1, D4.2 (A), S1.2, U1.1 (VIN), U1.3 (EN)
/CHIP_PU: C6.1, C9.2, R3.2, SW1.1, SW1.2, U3.8 (EN/CHIP_PU)
/GPIO3: J1.2, R1.1, U3.6 (GPIO3/ADC1_CH3)
/GPIO8: D1.4 (DIN), R2.2, U3.22 (GPIO8)
/GPIO9: C13.2, SW2.1, SW2.2, U3.23 (GPIO9)
/SCA: R4.1, U2.3 (SDI), U3.21 (GPIO7)
/SCL: R5.1, U2.4 (SCK), U3.20 (GPIO6)
/USB_D+: D2.2 (I/O1), J2.A6 (DP1), J2.B6 (DP2), U3.27 (GPIO19/USB_D+)
/USB_D-: D2.3 (I/O2), J2.A7 (DN1), J2.B7 (DN2), U3.26 (GPIO18/USB_D-)
GND: C1.2, C2.1, C3.2, C4.2, C5.2, C6.2, C7.2, C8.2, C9.1, C10.2, C11.2, C12.2, C13.1, D1.3 (VSS), D2.1 (GND), J1.3, J2.A1_B12 (GND), J2.B1_A12 (GND), J2.S1 (SHELL_GND), J2.S2 (SHELL_GND), J2.S3 (SHELL_GND), J2.S4 (SHELL_GND), J3.2, R6.1, R7.2, R9.1, R10.2, R11.1, R13.2, SW1.3, SW1.4, SW2.3, SW2.4, U1.2 (GND), U2.1 (GND), U2.5 (SDO), U2.7 (GND), U3.1 (GND), U3.2 (GND), U3.11 (GND), U3.14 (GND), U3.36 (GND), U3.37 (GND), U3.38 (GND), U3.39 (GND), U3.40 (GND), U3.41 (GND), U3.42 (GND), U3.43 (GND), U3.44 (GND), U3.45 (GND), U3.46 (GND), U3.47 (GND), U3.48 (GND), U3.49 (GND), U3.50 (GND), U3.51 (GND), U3.52 (GND), U3.53 (GND), U4.3 (SEL), U4.4 (PROG2), U4.9 (~TE), U4.10 (V_{SS}), U4.11 (V_{SS}), U4.21 (V_{SS})
unnamed: C11.1, S1.3, U4.1 (OUT), U4.20 (OUT)
unnamed: D3.1 (K), R12.2
unnamed: D4.1 (K), R14.2
unnamed: D5.1 (K), R15.2
unnamed: F1.1, J2.A4_B9 (VBUS), J2.B4_A9 (VBUS)
unnamed: J2.A5 (CC1), R7.1
unnamed: J2.B5 (CC2), R6.2
unnamed: C12.1, J3.1, U4.14 (V_{BAT}), U4.15 (V_{BAT}), U4.16 (V_{BAT_SENSE})
unnamed: R10.1, U4.13 (PROG1)
unnamed: R11.2, U4.12 (PROG3)
unnamed: R14.1, U4.8 (STAT1/~LBO)
unnamed: R15.1, U4.7 (STAT2)
unnamed: R13.1, U4.5 (THERM)
unnamed: R8.1, R9.2, U4.2 (VPCC)
unnamed: R12.1, U4.6 (~PG)
VCC: C10.1, D3.2 (A), D5.2 (A), F1.2, R8.2, U4.17 (CE), U4.18 (IN), U4.19 (IN)

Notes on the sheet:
WS2812B
Regulator
Lipo Charger and Power Parth
USB - OTG
ESP32-C3-MINI-1-H4
BME280
Switches
Ruff Current Draw esp32-c3 Wifi BLE = 350mA BME280 = 3.6 μA 0.0036mA DS18B20 = 1.5 mA WS2812B = 1μA 0.001mA PRTR5V0U2X = 100nA 0.000099mA AP2112 = 600mA = MCP73871 = 3750μA 3.75mA total = 355.254699mA (max out put from reg AP2112 = 600mA)
DS18B20 board Connection

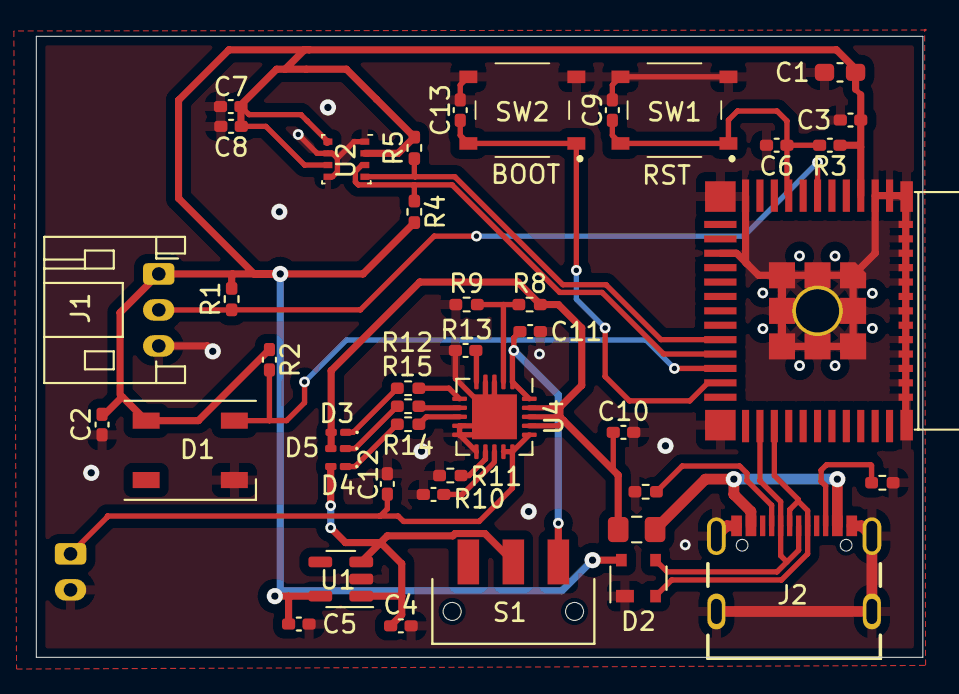
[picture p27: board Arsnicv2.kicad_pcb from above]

Board: 2 copper layers, 49.3 x 34.5 mm, 44 parts (1 on the bottom side), 27 nets.

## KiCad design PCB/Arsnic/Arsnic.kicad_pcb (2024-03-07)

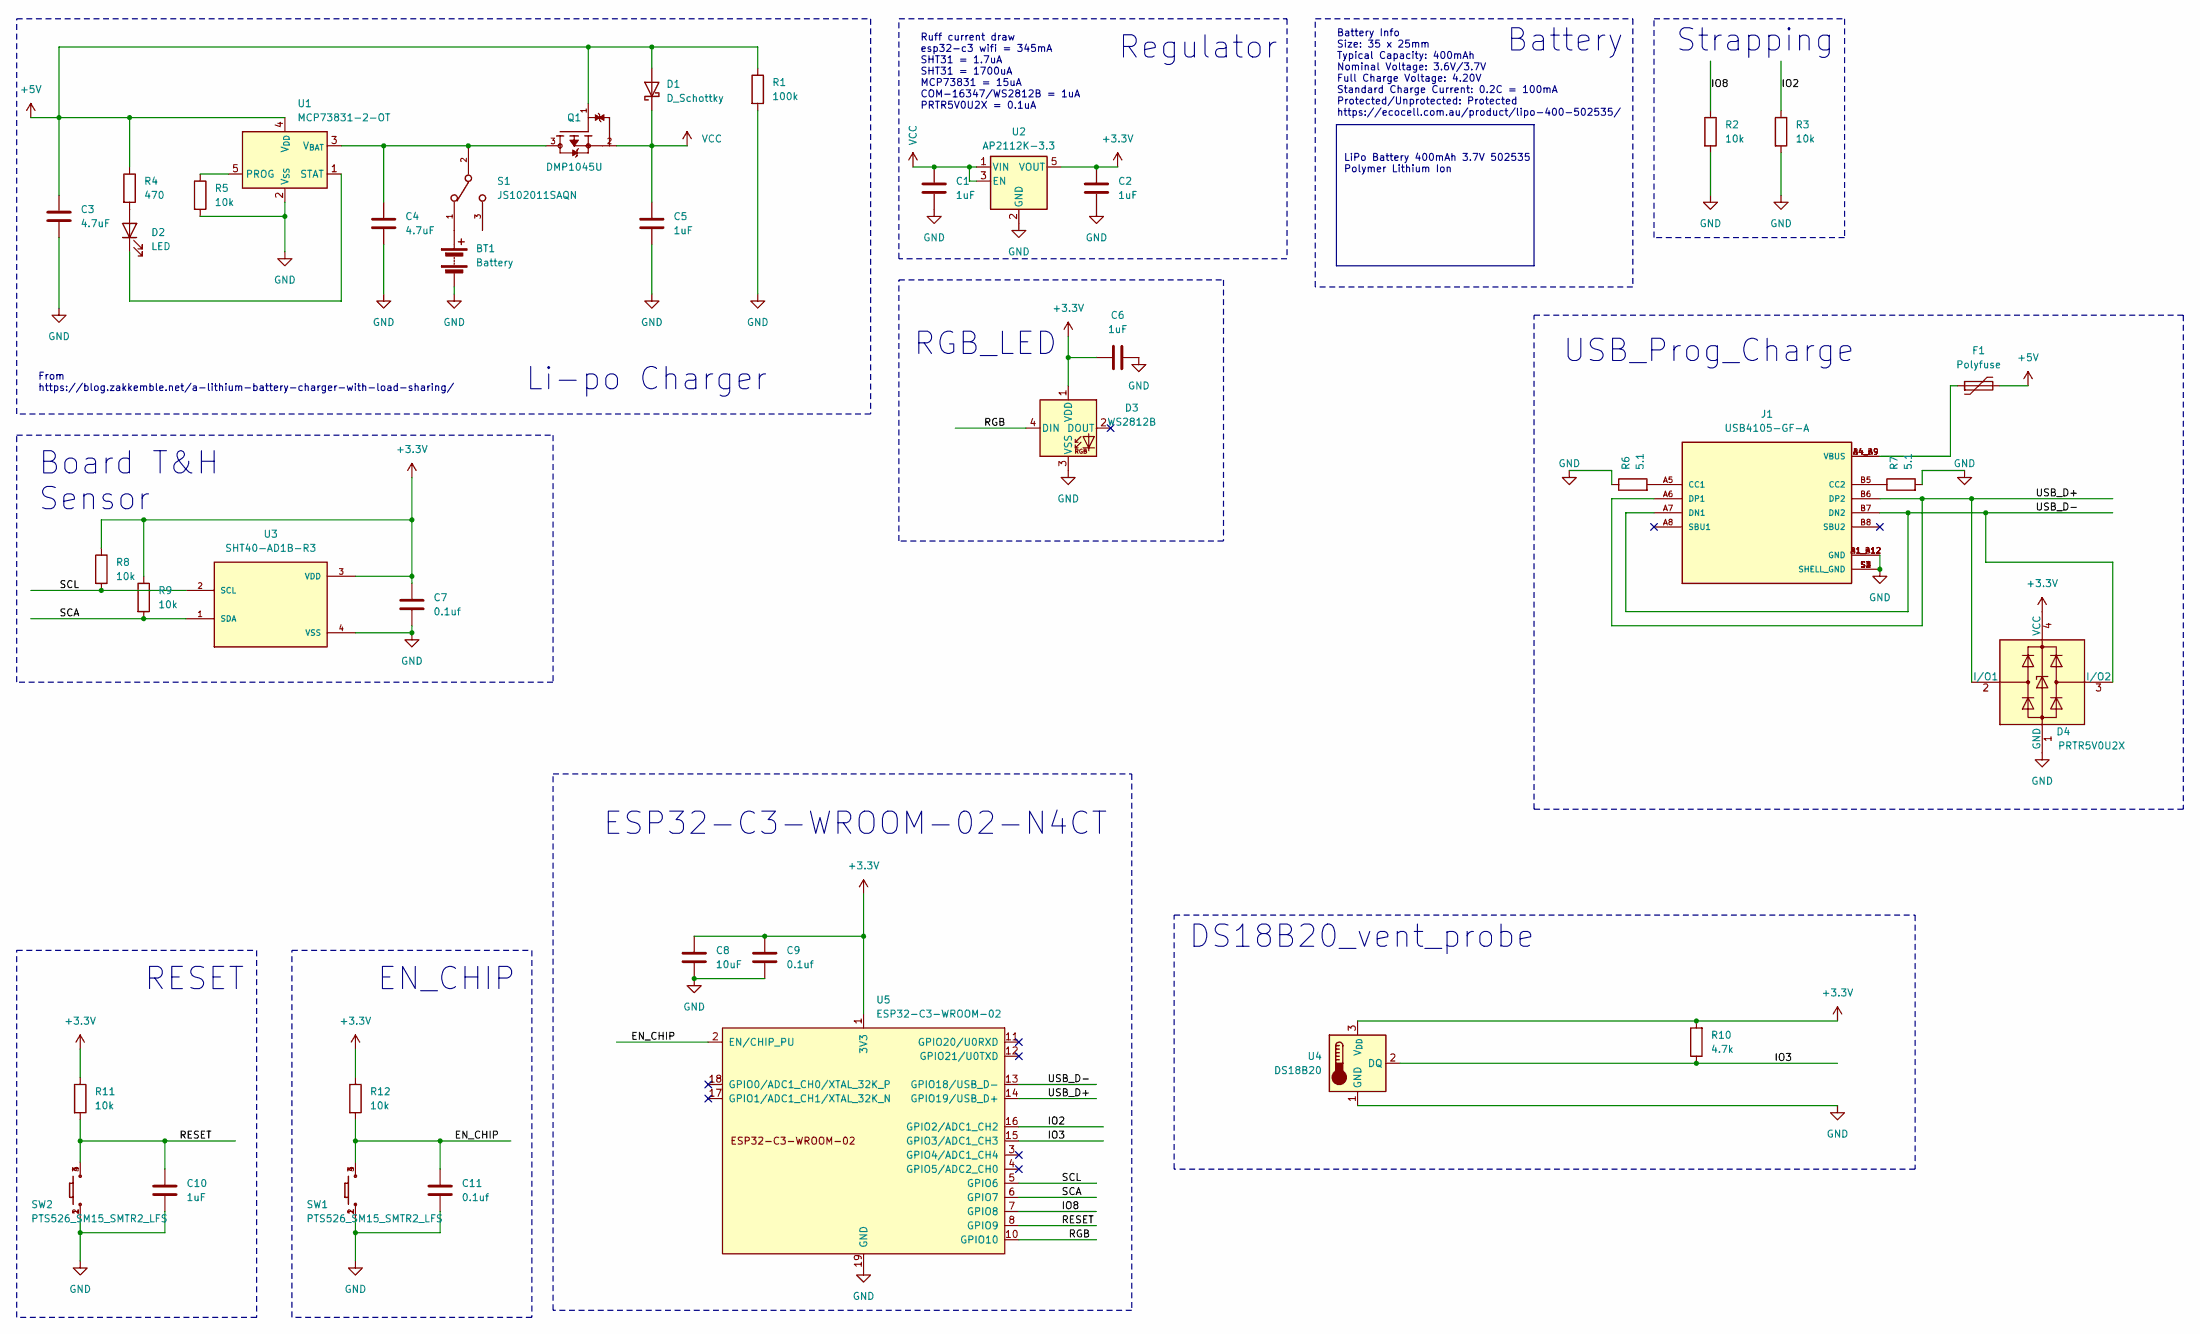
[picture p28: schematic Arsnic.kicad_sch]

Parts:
BT1: Battery; LED_D2.0mm_W4.8mm_H2.5mm_FlatTop; PartNumber LIPO-400-502535
C1, C2, C5, C6, C10: 1uF; C_0402_1005Metric_Pad0.74x0.62mm_HandSolder; DigiKeyPN 1276-1076-1-ND - Cut Tape (CT)
C3, C4: 4.7uF; C_0402_1005Metric_Pad0.74x0.62mm_HandSolder; DigiKeyPN 1276-1481-1-ND - Cut Tape (CT)
C7, C9, C11: 0.1uf; C_0402_1005Metric_Pad0.74x0.62mm_HandSolder; DigiKeyPN 478-11504-1-ND - Cut Tape (CT)
C8: 10uF; C_0603_1608Metric_Pad1.08x0.95mm_HandSolder; DigiKeyPN 1276-1119-1-ND - Cut Tape
D1: D_Schottky; D_SOD-123; DigiKeyPN B130LAW-FDICT-ND - Cut Tape (CT)
D2: LED; LED_Rectangular_W3.0mm_H2.0mm; DigiKeyPN 754-1901-ND
D3: WS2812B; LED_WS2812B_PLCC4_5.0x5.0mm_P3.2mm; DigiKeyPN 1568-COM-16347CT-ND - Cut Tape (CT)
D4: PRTR5V0U2X; SOT-143; DigiKeyPN 1727-3884-1-ND - Cut Tape (CT)
F1: Polyfuse; Fuse_1206_3216Metric_Pad1.42x1.75mm_HandSolder; DigiKeyPN F2112CT-ND - Cut Tape (CT)
J1: USB4105-GF-A; GCT_USB4105-GF-A; DigiKeyPN 2073-USB4105-GF-ACT-ND - Cut Tape (CT)
Q1: DMP1045U; SOT91P240X110-3N; DigiKeyPN DMP1045U-7DICT-ND - Cut Tape (CT)
R1: 100k; R_0402_1005Metric_Pad0.72x0.64mm_HandSolder; DigiKeyPN 1292-WR04X104JTLCT-ND - Cut Tape (CT)
R2, R3, R5, R8, R9, R11, R12: 10k; C_0402_1005Metric_Pad0.74x0.62mm_HandSolder; DigiKeyPN 311-10.0KLRCT-ND - Cut Tape (CT)
R4: 470; R_0402_1005Metric_Pad0.72x0.64mm_HandSolder; DigiKeyPN 1292-WR04X4700FTLCT-ND - Cut Tape (CT)
R6, R7: 5.1; C_0402_1005Metric_Pad0.74x0.62mm_HandSolder; DigiKeyPN 311-5.1JRCT-ND - Cut Tape (CT)
R10: 4.7k; R_0402_1005Metric_Pad0.72x0.64mm_HandSolder; DigiKeyPN 311-4.7KLRCT-ND - Cut Tape (CT)
S1: JS102011SAQN; SW_JS102011SAQN; DigiKeyPN 401-1999-1-ND - Cut Tape (CT)
SW1, SW2: PTS526_SM15_SMTR2_LFS; PTS526SM15SMTR2LFS; DigiKeyPN CKN12220-1-ND - Cut Tape (CT)
U1: MCP73831-2-OT; SOT-23-5; DigiKeyPN MCP73831T-2ACI/OTCT-ND - Cut Tape (CT)
U2: AP2112K-3.3; SOT-23-5; DigiKeyPN AP2112K-3.3TRG1DICT-ND - Cut Tape (CT)
U3: SHT40-AD1B-R3; SHT4X; DigiKeyPN 1649-SHT40-AD1B-R3CT-ND
U4: DS18B20; TO-92_Inline; DigiKeyPN 1528-1592-ND
U5: ESP32-C3-WROOM-02; DigiKeyPN 1965-ESP32-C3-WROOM-02-N4CT-ND

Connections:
+3.3V: C2.1, C6.1, C7.1, C8.1, C9.1, D3.1 (VDD), D4.4 (VCC), R8.1, R9.1, R10.2, R11.1, R12.1, U2.5 (VOUT), U3.3 (VDD), U4.3 (V_{DD}), U5.1 (3V3)
+5V: C3.1, D1.2 (A), F1.2, Q1.1, R1.1, R4.1, U1.4 (V_{DD})
/EN_CHIP: C11.1, R12.2, SW1.3, SW1.4, U5.2 (EN/CHIP_PU)
/IO2: R3.1, U5.16 (GPIO2/ADC1_CH2)
/IO3: R10.1, U4.2 (DQ), U5.15 (GPIO3/ADC1_CH3)
/IO8: R2.1, U5.7 (GPIO8)
/RESET: C10.1, R11.2, SW2.3, SW2.4, U5.8 (GPIO9)
/RGB: D3.4 (DIN), U5.10 (GPIO10)
/SCA: R9.2, U3.1 (SDA), U5.6 (GPIO7)
/SCL: R8.2, U3.2 (SCL), U5.5 (GPIO6)
/USB_D+: D4.2 (I/O1), J1.A6 (DP1), J1.B6 (DP2), U5.14 (GPIO19/USB_D+)
/USB_D-: D4.3 (I/O2), J1.A7 (DN1), J1.B7 (DN2), U5.13 (GPIO18/USB_D-)
GND: BT1.2 (-), C1.2, C2.2, C3.2, C4.2, C5.2, C6.2, C7.2, C8.2, C9.2, C10.2, C11.2, D3.3 (VSS), D4.1 (GND), J1.A1_B12 (GND), J1.B1_A12 (GND), J1.S1 (SHELL_GND), J1.S2 (SHELL_GND), J1.S3 (SHELL_GND), J1.S4 (SHELL_GND), R1.2, R2.2, R3.2, R5.2, R6.1, R7.2, SW1.1, SW1.2, SW2.1, SW2.2, U1.2 (V_{SS}), U2.2 (GND), U3.4 (VSS), U4.1 (GND), U5.9 (GND), U5.19 (GND)
unnamed: BT1.1 (+), S1.1
unnamed: D2.2 (A), R4.2
unnamed: D2.1 (K), U1.1 (STAT)
unnamed: F1.1, J1.A4_B9 (VBUS), J1.B4_A9 (VBUS)
unnamed: J1.A5 (CC1), R6.2
unnamed: J1.B5 (CC2), R7.1
unnamed: R5.1, U1.5 (PROG)
unnamed: C4.1, Q1.3, S1.2, U1.3 (V_{BAT})
VCC: C1.1, C5.1, D1.1 (K), Q1.2, U2.1 (VIN), U2.3 (EN)

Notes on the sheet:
Battery
RESET
USB_Prog_Charge
Li-po Charger
EN_CHIP
Board T&H Sensor
ESP32-C3-WROOM-02-N4CT
Regulator
Ruff current draw esp32-c3 wifi = 345mA SHT31 = 1.7uA SHT31 = 1700uA MCP73831 = 15uA COM-16347/WS2812B = 1uA PRTR5V0U2X = 0.1uA
Battery Info Size: 35 x 25mm Typical Capacity: 400mAh Nominal Voltage: 3.6V/3.7V Full Charge Voltage: 4.20V Standard Charge Current: 0.2C = 100mA Protected/Unprotected: Protected https://ecocell.com.au/product/lipo-400-502535/
Strapping
DS18B20_vent_probe
From https://blog.zakkemble.net/a-lithium-battery-charger-with-load-sharing/
RGB_LED
LiPo Battery 400mAh 3.7V 502535 Polymer Lithium Ion

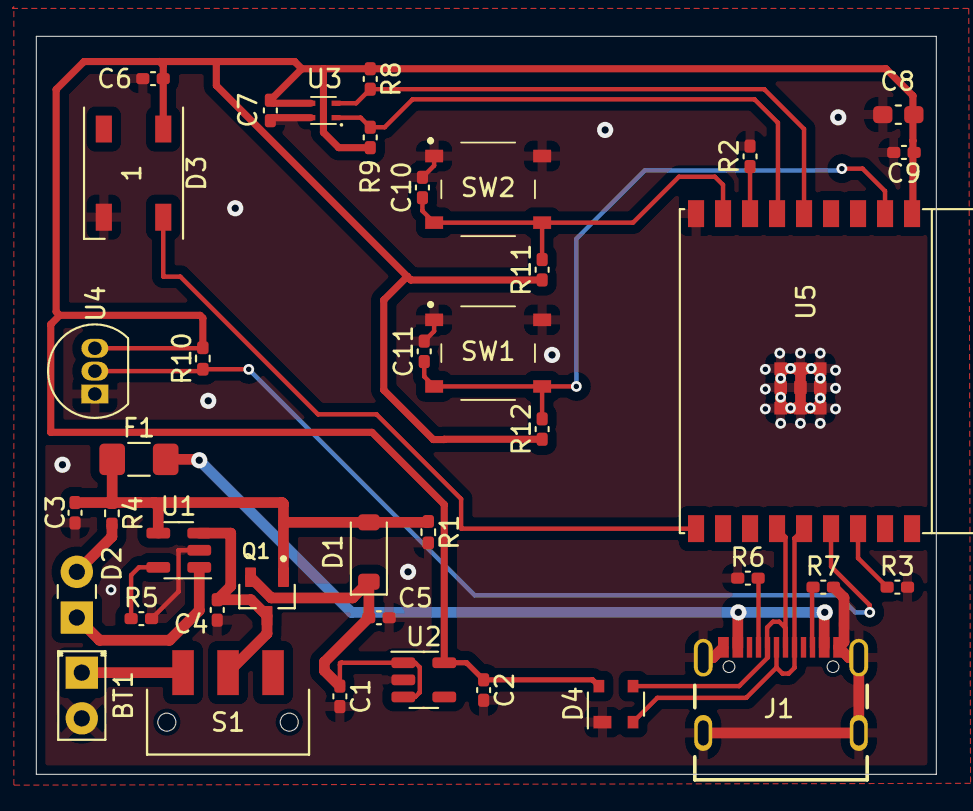
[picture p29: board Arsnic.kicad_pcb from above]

Board: 2 copper layers, 50.0 x 41.0 mm, 39 parts (0 on the bottom side), 22 nets.

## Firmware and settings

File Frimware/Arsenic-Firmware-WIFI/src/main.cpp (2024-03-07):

#include <Arduino.h>
#include <LittleFS.h>
#include <SPI.h>
#include <WiFi.h>
#include <Wire.h>
#include <OneWire.h>
#include <DallasTemperature.h>
#include <Bme280.h>
#include <WS2812Led.h>
#include <MAX17048.h>
#include <AsyncTCP.h>
#include <ESPAsyncWebServer.h>
#include <Arduino_JSON.h>
#include <config.h>
#include <DNSServer.h>
#include <r134a.h>
#include <r1234yf.h>
#include <r744.h>
#include <hychill30.h>

//============Device Setup============

WS2812Led wsLED(WS2812LedPin, 1);

OneWire oneWire(ONE_WIRE_BUS);

DallasTemperature sensors(&oneWire);
DeviceAddress tempDeviceAddress;

Bme280TwoWire bme280;

MAX17048 pwr_mgmt;

//============Wifi/Web Server Setup============
//Dns settings
DNSServer dnsServer;

//Strings to hold device credentials 
String SSID; 
String PWD;
String UNITS;

//Set the device's IP
IPAddress apIP(192, 168, 4, 1);

// Create AsyncWebServer object on port 80
AsyncWebServer server(80);

// Create an Event Source on /events
AsyncEventSource events("/events");

// Json Variable to Hold Sensor Readings
JSONVar readings;
JSONVar wifi;
JSONVar newWifi;

// Timer variables
unsigned long lastTime = 0;  
unsigned long timerDelay = 3000; //3sec

//============Vars============
bool reboot = false;
bool clientConnected = false;

uint32_t Freq = 0;

//============Temp to Kpa classes============
r134a r134a_1;
r1234yf r1234yf_1;
r744 r744_1;
hychill30 hychill30_1;

void restartDevice()
{
  ESP.restart();
}

void saveConfig(String newSsid, String newPwd, String newUnits)
{ 
  File file = LittleFS.open("/config.txt", "w");

  if(!file)
   {
    Serial.println("Config not found!!!!");
    Serial.println("Unable to wtite wifi SSID, PWD and Units Please reflash");
    Serial.println("Device will restart");
    reboot = true;
    
   }
  String data = (String (newSsid.c_str()) + '\n' + String (newPwd.c_str()) + '\n' + String (newUnits.c_str()));
  file.print(data);
  
  file.close();

  Serial.println("New SSID: " + newSsid + ", new Password: " + newPwd + " and new Units: " + newUnits + " written"); 
  Serial.println("Device going down for a reboot");
  reboot = true;
}

void readConfig()
{
  File file = LittleFS.open("/config.txt", "r");
  
  //Check if the file exists
   if(!file)
   {
    Serial.println("Config not found!!!!");
    Serial.println("Unable to set wifi SSID and PWD, Please reflash");
    Serial.println("Device will restart");
    reboot = true;
   }

   int line = 0;

   while (file.available())
   {
    if (line == 0)
    {
      String ssdiString=file.readStringUntil('\n');
      SSID = ssdiString.c_str();
    }

    if (line == 1)
    {
      String pwdString=file.readStringUntil('\n');
      PWD = pwdString.c_str();
    }

    if (line == 2)
    {
      String unitsString=file.readStringUntil('\n');
      UNITS = unitsString.c_str();
    }

    line++;
   }
   file.close();
}

void wifiClientConnected(WiFiEvent_t event, WiFiEventInfo_t info)
{
  clientConnected = true;
  Serial.println("Wifi Client Connected");
  wsLED.Clear();
  //delay (500);
  wsLED.Brightness(20);
  wsLED.UpdateAll(wsLED.GREEN);
  delay (500);
}

void wifiClientDisconnected(WiFiEvent_t event, WiFiEventInfo_t info)
{
  clientConnected = false;
  Serial.println("Wifi Client Disconnected");
  wsLED.Clear();
  //delay (500);
  wsLED.Brightness(20);
  wsLED.UpdateAll(wsLED.YELLOW);
  delay (500);
}

void initWiFi() 
{
  Serial.println("Setting as soft access point mode");
  WiFi.mode(WIFI_AP);
  WiFi.softAPConfig(apIP, apIP, IPAddress(255, 255, 255, 0));
  delay(250);

  if (debug)
  {
  Serial.println("SSID:" + String(SSID));
  Serial.println("Password:" + String(PWD));
  }
  WiFi.softAP(SSID.c_str(), PWD.c_str());
  WiFi.hostname(SSID);
  delay(250);

  IPAddress IP = WiFi.softAPIP();
  Serial.print("AP IP address:");
  Serial.println(IP);
  
  delay(250);
}

void initFS() 
{
  if (!LittleFS.begin()) {
    Serial.println("An error has occurred while mounting LittleFS");
    Serial.println("Device requires reflashing");
    reboot = true;
  }
  Serial.println("LittleFS mounted successfully");

}

String getHychill30Press()
{
  int aTemp;
  aTemp = round(bme280.getTemperature());

  String press = String(hychill30_1.pressure(aTemp));
  if(debug)
  {
    Serial.print("Hychill30 Pressure: ");
    Serial.print(press);
    Serial.println("Kpa");
  }

  return press;
}

String getR744Press()
{
  int aTemp;
  aTemp = round(bme280.getTemperature());

  String press = String(r744_1.pressure(aTemp));
  if(debug)
  {
    Serial.print("r744 Pressure: ");
    Serial.print(press);
    Serial.println("Kpa");
  }

  return press;
}

String getR1234yfPress ()
{
  int aTemp;
  aTemp = round(bme280.getTemperature());

  String press = String(r1234yf_1.pressure(aTemp));
  if(debug)
  {
    Serial.print("r1234yf Pressure: ");
    Serial.print(press);
    Serial.println("Kpa");
  }

  return press;
}

String getR134aPress()
{
  int aTemp;
  aTemp = round(bme280.getTemperature());

  String press = String(r134a_1.pressure(aTemp)); 

  if(debug)
  {
    Serial.print("r134a Pressure: ");
    Serial.print(press);
    Serial.println("Kpa");
  }

  return press;
}

String getWifiDetails()
{
  wifi["ssid"] = SSID;
  wifi["pwd"] = PWD;
  wifi["unit"] = UNITS;
  String jsonString = JSON.stringify(wifi);
  
  if (debug)
  {
  Serial.println(String(jsonString));
  }

  return jsonString;
}

String readVentTemp()
{
  sensors.requestTemperatures();
  int vTemp;
  vTemp = round(sensors.getTempCByIndex(0));

  if(debug)
  {
    Serial.print("Vent Probe Temperature Celsius:");
    Serial.print(vTemp);
    Serial.println("ºC");
  }
  return String(vTemp);
}

String readAtmosTemp()
{
  int aTemp;
  aTemp = round(bme280.getTemperature());

  if(debug)
  {
    Serial.print("Atmospheric Probe Temperature Celsius:");
    Serial.print(aTemp);
    Serial.println("ºC");
  }
  return String(aTemp);

}

String readAtmosHumidity()
{
  int aHumidity;
  aHumidity = bme280.getHumidity();

   if(debug)
  {
    Serial.print("Atmospheric Probe Humidity:");
    Serial.print(aHumidity);
    Serial.println(" %");
  }
  return String(aHumidity);
}

String readAtmosPressure()
{
  int aPressure;
  aPressure = bme280.getPressure();

   if(debug)
  {
    Serial.print("Atmospheric Probe Pressure:");
    Serial.print(aPressure);
    Serial.println("Pa");
  }
  return String(aPressure);
}

String readBatterySoc()
{
  int bSoc;
  bSoc = pwr_mgmt.percent();

   if(debug)
  {
    Serial.print("Battery SOC:");
    Serial.print(bSoc);
    Serial.println("%");
  }
  return String(bSoc);
}

String getSensorReadings()
{
  readings["ventTemp"] = readVentTemp();
  readings["atmosTemp"] = readAtmosTemp();
  readings["atmosHum"] = readAtmosHumidity();
  readings["atmosPress"] = readAtmosPressure();
  readings["battSoc"] = readBatterySoc();
  readings["r134aKpa"] = getR134aPress();
  readings["r1234yfKpa"] = getR1234yfPress();
  readings["r744Kpa"] = getR744Press();
  readings["hychill30"] = getHychill30Press();

String jsonString = JSON.stringify(readings);

if(debug)
{
  Serial.println("Websocket data " + String(jsonString));
}

return jsonString;
}

String getWifiDetailsDevice()
{
  wifi["ssid"] = SSID;
  wifi["pwd"] = PWD;
  wifi["unit"] = UNITS;
  String jsonString = JSON.stringify(wifi);
  
  if (debug)
  {
  Serial.println(String(jsonString));
  }

  return jsonString;
}

class CaptiveRequestHandler : public AsyncWebHandler {
public:
  CaptiveRequestHandler() {}
  virtual ~CaptiveRequestHandler() {}

  bool canHandle(AsyncWebServerRequest *request){
    //request->addInterestingHeader("ANY");
    return true;
  }

  void handleRequest(AsyncWebServerRequest *request) {
    request->send(LittleFS, "/index.html", "text/html"); 
  }
};

void setup() 
{
  //Set cpu Frequency 
  setCpuFrequencyMhz(cpuFreq);

  Freq = getCpuFrequencyMhz();

  //Change the WS2812Led to RED to indicate device booting.
  wsLED.Clear();
  //delay (500);
  wsLED.Brightness(20);
  wsLED.UpdateAll(wsLED.RED);

  Serial.begin(115200);

  Serial.println("*****************************************");
  Serial.println("*                                       *");
  Serial.println("*     ARSENIC                           *");
  Serial.println("*     Smart HVAC TEMP PROBE             *");
  Serial.println("*     By Rick spooner (spoonie)         *");
  Serial.println("*                                       *");
  Serial.println("*****************************************");
  Serial.println("");
  Serial.println("");
  Serial.println("");

  Serial.println("Version: " + String(fwVersion));

  Serial.println("CPU Set to " + String(Freq) + " Mhz");

  initFS();
  readConfig();
  
  Wire.begin(I2C_SDA, I2C_SCL);
  Serial.println("Wire up");

  //sensors.begin();
  //Serial.println("Sensors DB up");

  bme280.begin(Bme280TwoWireAddress::Primary);
  bme280.setSettings(Bme280Settings::indoor());
  Serial.println("BME280 up");

  pwr_mgmt.attatch(Wire);
  Serial.println("MAX17048 up");

  initWiFi();

  WiFi.onEvent(wifiClientDisconnected, WiFiEvent_t::ARDUINO_EVENT_WIFI_AP_STADISCONNECTED);
  WiFi.onEvent(wifiClientConnected, WiFiEvent_t::ARDUINO_EVENT_WIFI_AP_STACONNECTED);

   // Web Server Root URL
  server.on("/", HTTP_GET, [](AsyncWebServerRequest *request)
  {
    request->send(LittleFS, "/index.html", "text/html");

  });

  server.serveStatic("/", LittleFS, "/");
  
  // Request for the latest sensor readings
  server.on("/readings", HTTP_GET, [](AsyncWebServerRequest *request){
    String json = getSensorReadings();
    request->send(200, "application/json", json);
    json = String();
  });

  // Send wifi details to webpage
  server.on("/wifi", HTTP_GET, [](AsyncWebServerRequest *request){
    String json = getWifiDetailsDevice();
    request->send(200, "application/json", json);
    json = String();
  });

  // Get user updated wifi details
  server.on("/newWifi", HTTP_POST, [](AsyncWebServerRequest *request){
    String newSsid = request->arg("ssid");
    String newPwd = request->arg("pwd");
    String newUnits = request->arg("unit");

    Serial.println("Recived device new SSID: " + newSsid + " & " + "new device password: " + newPwd + " & " + "new device Units" + newUnits);

    saveConfig(newSsid, newPwd, newUnits);
  });

  // When user connets via webpage
  events.onConnect([](AsyncEventSourceClient *client){
    if(client->lastId())
    {
      Serial.printf("Client reconnected! Last message ID that it got is: %u\n", client->lastId());
    }
    // send event with message "hello!", id current millis
    // and set reconnect delay to 1 second
    client->send("hello!", NULL, millis(), 10000);
    clientConnected = true;
  });

  server.addHandler(&events);
  
  dnsServer.setErrorReplyCode(DNSReplyCode::NoError);
  dnsServer.start(53, "*", WiFi.softAPIP());
   
  // Start web server 
  server.begin();
  Serial.println("Web Server Up");

  server.addHandler(new CaptiveRequestHandler()).setFilter(ON_AP_FILTER);//only when requested from AP

  wsLED.Clear();
  //delay (500);
  wsLED.Brightness(20);
  wsLED.UpdateAll(wsLED.YELLOW); 
}

void loop() 
{
  if(clientConnected)
  { 
    dnsServer.processNextRequest();

    if ((millis() - lastTime) > timerDelay) 
    {
      // Send Events to the client with the Sensor Readings Every 3 seconds
      events.send("ping",NULL,millis());
      events.send(getSensorReadings().c_str(),"new_readings" ,millis());

      lastTime = millis();
    }
  }
  else
  {
    delay(500);
  }
  
  if(reboot)
  {
    restartDevice();
  }
}

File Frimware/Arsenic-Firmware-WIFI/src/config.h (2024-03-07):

#ifndef config_H    
#define config_H   

#define defaultDeviceName "Smart Hvac Probe"

#define fwVersion "0.2"

#define cpuFreq 80

#define I2C_SDA 7
#define I2C_SCL 6
#define ONE_WIRE_BUS 3
#define WS2812LedPin 10

#define ATMOS_TEMP_OFFSET 0
#define VENT_TEMP_OFFSET 0 

bool debug = false;

#endif 
